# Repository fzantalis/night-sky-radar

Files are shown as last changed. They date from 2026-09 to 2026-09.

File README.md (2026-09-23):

# Night Sky Radar

A standalone desk instrument that shows which satellites are overhead right
now — and, more usefully, which of them you could actually *see* with the naked
eye if you walked outside.

No cloud service and no phone app. The device fetches orbital elements over
WiFi and propagates them itself with SGP4, so once it has data it keeps working
offline.

Two LEDs count down to the next visible pass, so you don't have to watch the
screen. Wave your hand to switch between satellites and asteroids.

---

## What it shows

**SKY mode** — a map of the sky above you. The centre is straight overhead, the
rim is the horizon, and north is up. A dot's size is its brightness; a pale
blue dot means *visible right now, go outside*. Meteor shower radiants appear as
soft patches when a shower is active and the sky is dark.

Only four conditions together make a satellite visible, and the device checks
all of them: it is more than 10° above the horizon, the sun is more than 6°
below yours, the satellite is still in sunlight, and it is brighter than
magnitude +4.5.

**NEO mode** — asteroid close approaches from NASA/JPL. Both axes change
meaning: the radius is the miss distance (the rim is 10 lunar distances), and
the angle is *when* it happens across a 30-day window. The ring at 1 lunar
distance is the Moon's orbit — anything inside it passes closer than the Moon.

**The LEDs** — one lit means a visible pass within 10 minutes, both mean within
5, and the pulse quickens as it approaches. They work in both modes.

---

## Parts

| Part | Notes |
|---|---|
| ESP32-S3-DevKitC-1 | ESP32-S3-WROOM-1 **N16R8** (16 MB flash, 8 MB PSRAM). The PSRAM is required — the framebuffer alone is 253 KB |
| 2.1" round TFT, 360×360 | **GC9B72** controller, 4-wire SPI |
| PAJ7620U2 gesture sensor | I²C, address `0x73` |
| 2 × WS2812 | Cut from an addressable strip |
| USB-C cable | Powers and flashes the board |

The `enclosure*.stl` files and the FreeCAD source are in the repository root.

---

## Wiring

> **Both the display and the gesture sensor are 3.3 V only.** 5 V on either
> will destroy it. Neither breakout has a regulator.

> **Never use GPIO 26–37 on an N16R8.** They are wired to the SPI flash and the
> octal PSRAM. 35/36/37 are broken out on the header, which makes them an easy
> trap.

**Display (GC9B72)**

| Display | ESP32-S3 |
|---|---|
| `VCC` | **3V3** |
| `GND` | GND |
| `SCL` | GPIO 12 |
| `SDA` | GPIO 11 |
| `CS` | GPIO 10 |
| `DC` | GPIO 13 |
| `RST` | GPIO 14 |
| `BL` | GPIO 9 |
| `SDO`, `TE` | leave unconnected |

`CS`/`SDA`/`SCL` are the S3's native SPI pins. Keep these leads short — the
panel is good for about 20 MHz on jumper wires.

**Gesture sensor (PAJ7620U2)**

| Sensor | ESP32-S3 |
|---|---|
| `VCC` | **3V3** |
| `GND` | GND |
| `SDA` | GPIO 17 |
| `SCL` | GPIO 18 |
| `INT` | GPIO 16 |

**LEDs (2 × WS2812)**

| Strip | ESP32-S3 |
|---|---|
| `+5V` | **3V3**, not 5V — see below |
| `GND` | GND |
| `DIN` | GPIO 15 |

The strip runs from 3.3 V deliberately. A WS2812 needs a logic high above
0.7 × VDD; on a 5 V supply that is 3.5 V, which an ESP32 GPIO cannot reach, so
5 V operation is marginal. At 3.3 V the threshold is 2.31 V and the same pin
clears it comfortably. It is slightly under the part's nominal minimum, which
costs nothing at the low brightness this instrument uses.

The strip is directional — wire the `DIN` end, not `DO`.

All pin assignments live in [`src/Pins.h`](src/Pins.h).

---

## Quick start

You need [PlatformIO](https://platformio.org/).

```bash
git clone https://github.com/fzantalis/night-sky-radar.git
cd night-sky-radar
cp src/secrets.h.example src/secrets.h     # then fill in your WiFi
pio run -t upload                          # firmware
pio run -t uploadfs                        # web UI files
```

On first boot the panel shows `SET LOCATION`. Find the device's IP in the
serial log (115200 baud), then open `http://<ip>/config` and enter your
latitude, longitude and altitude.

`http://<ip>/` gives the same dial in a browser — useful before you have the
panel wired, and it draws from the identical data the panel does.

**Controls.** Swipe left/right to change mode, up/down for brightness, wave to
wake the screen. In the browser, the arrow keys and space do the same. The BOOT
button also switches mode, as a fallback when no gesture sensor is attached.

---

## Tests

```bash
pio test -e native
```

224 tests covering the orbital mathematics, visibility rules, pass prediction
and data parsing. They run on the host, with no board attached — everything in
`lib/core/` is deliberately free of Arduino and ESP-IDF headers so it can be
tested that way.

---

## Data sources

| Source | Used for |
|---|---|
| [CelesTrak](https://celestrak.org/) | Orbital elements (TLE) |
| [NASA/JPL SBDB](https://ssd-api.jpl.nasa.gov/doc/cad.html) | Asteroid close approaches |
| [IMO](https://www.imo.net/) | Meteor shower almanac |

Provenance for every constant and data source, including the magnitude and
diameter relations, is recorded in [`docs/third-party/`](docs/third-party/).

---

## Licence

MIT — see [LICENSE](LICENSE).

This project includes a vendored copy of the
[dnwrnr/sgp4](https://github.com/dnwrnr/sgp4) library under the Apache License
2.0. See [NOTICE](NOTICE) and
[`lib/core/src/sgp4/LICENSE`](lib/core/src/sgp4/LICENSE).

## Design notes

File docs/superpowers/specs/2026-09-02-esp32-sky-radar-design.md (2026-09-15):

# ESP32-S3 Sky Radar — Design

**Date:** 2026-09-02
**Status:** Approved for implementation planning
**Scope of this spec:** Milestones M0–M2. M3–M7 are sketched for architectural context only.

## 1. Purpose

A standalone desk instrument that shows what is above you in near-Earth space on a circular radar-style display, with emphasis on objects you could actually walk outside and see with the naked eye.

The device is standalone: it fetches orbital elements a couple of times a day and does all propagation, visibility determination and projection itself. It keeps working through a router reboot. It is not a thin client for a tracking service.

Hardware target is an ESP32-S3-DevKitC-1 N16R8 (16 MB flash, 8 MB octal PSRAM). The final display is a GC9A01 240x240 round IPS SPI panel, not yet purchased. Until it arrives, the same renderer output is served to a browser as a 240x240 panel simulator.

## 2. Scope decisions

### In scope for M0–M2

- ISS and Tiangong tracking (CelesTrak `stations` group)
- The ~160 brightest catalogued objects (CelesTrak `visual` group)
- On-device SGP4 propagation
- Naked-eye visibility determination
- Forward pass prediction with countdowns
- A 240x240 circular web renderer that obeys the physical panel's constraints
- Native (PC) unit tests for the whole orbital/visibility core

### Deferred, but the architecture must not preclude them

- **M3** Starlink train detection — stream-filter the ~8000-object `starlink` group.
  **Corrected 2026-09-04:** the original wording said to filter by COSPAR launch
  designator, keeping launches from the last ~14 days. That is not implementable — a
  designator encodes the launch YEAR and the Nth launch of that year, never a date.
  The physically correct discriminator is **mean motion**: a fresh batch sits near
  350 km and is still raising orbit (~15.6 rev/day) while operational Starlinks sit
  at ~550 km (~15.06). Low and clustered is exactly what makes a train visible, and
  low is what mean motion measures. The designator remains useful as a grouping key
  for members of one launch.
- **M4** Meteor shower radiants — static almanac, rendered as a glowing sector
- **M5** NEO mode — JPL CAD API, Earth-centred, 10 lunar distances at the rim, time-scrubbed over 30 days rather than rendered live

  **Implemented 2026-09-05, with the time scrub resolved as an axis rather than a control.**
  "Time-scrubbed" left open how time reaches the dial. Making it a scrub *control*
  would have needed an input the device does not have and a renderer that holds its
  own clock state, breaking the dumb-polar-plotter rule. Instead **the angle itself is
  time**: 0 degrees is now, a full turn is the 30-day window, and radius is the miss
  distance with the rim at 10 lunar distances. Approaches march round towards the
  fixed "now" hand as their date arrives, so the whole window is legible at once with
  no control at all.

  Two further decisions, both departures worth recording:

  - **NEO mode does not require an observer location.** A close approach is an
    Earth-centred event, so `build()` checks the mode *before* the `hasLocation()`
    gate and the setup nag is suppressed there. The dial is meaningful on a device
    that has never been told where it is.
  - **Mode is not persisted.** After a power cut the instrument returns to SKY,
    because "is anything up right now" is the question it exists to answer.

  Switching is BOOT on the device and arrow keys or space in the browser, both
  through `/api/mode` so the device and every open browser agree on one mode.
  See `docs/third-party/NEO-CAD-PROVENANCE.md`.
- **M6** Panel renderer, gesture input, status LEDs

  **Implemented and verified on hardware 2026-09-15.** The hardware arrived
  different from the plan in all three respects, and the central bet of section
  3.1 is what absorbed it: because the core hands renderers finished
  `(r, theta)` pairs, **not one line of orbital maths changed**.

  - **Panel: GC9B72 360x360, not GC9A01 240x240.** LovyanGFX 1.2.29 carries a
    `Panel_GC9B72`, so no vendored driver. The framebuffer is 253 KB and lives
    in PSRAM; it cannot fit in internal RAM beside WiFi and ~200 tracked
    objects. SPI runs at 20 MHz rather than the bus maximum, because too-fast
    SPI does not fail cleanly — it yields intermittently corrupt pixels that
    read as a rendering bug.
  - **Input: PAJ7620U2 gesture sensor, not a rotary encoder or button.** Left
    and right switch mode, up and down walk a brightness ladder, wave clears
    the idle dim. BOOT survives as a fallback used only when the sensor does
    not answer on I2C.
  - **Status: two WS2812s, not a ring and not the onboard RGB.** The onboard
    part proved unreachable from software (see `tools/ledprobe`). Two pixels
    make the alert a countdown bar rather than a lamp.

  Three defects only the real hardware could have surfaced, all recorded in
  commit `e926ca6`: an RMT deadlock that hung the boot silently, panel colour
  flags that were doubly wrong, and the LED bar going dark in NEO mode because
  events were only attached on the SKY path.

- **M7** Captive-portal config, enclosure — gated on M6

**Revised 2026-09-04.** Two changes to the deferred list:

- **The NeoPixel bezel ring is dropped in favour of the board's own WS2812 on GPIO48**,
  and pulse notification moves forward from M7 into **M2**, where the visibility engine
  first makes "a pass worth alerting on" a real concept. The onboard LED loses the ring's
  rotating-sweep effects but keeps everything that matters (pulse, breathe, colour-code),
  needs no library (`neopixelWrite(RGB_BUILTIN, ...)` ships in the Arduino core), and draws
  ~5-10 mA dim-red against a 24-LED ring's ~720 mA at full white.
- **The magnetometer is deferred indefinitely** — see 3.4.

### Explicitly rejected

- **N2YO as a runtime data source.** Its REST API is well built, but sourcing positions from it makes the device a thin client that goes blank when WiFi hiccups, and binds the project to a free tier's rate limits. It is used instead as a **development-time test oracle** (see section 10).
- **Tracking all visible satellites server-side.** Loses the standalone quality that is the point of the project.
- **Meteors as tracked objects.** There is no per-meteor ephemeris. Only showers (radiant, peak date, ZHR) are real, and those are almanac data.
- **Starlink as a general naked-eye target.** Operational Starlinks with visors sit at roughly magnitude 5.5–7 and are not naked-eye objects. Only recently launched, still-clustered trains are worth displaying.

## 3. Architecture

### 3.1 The central decision

**Projection happens in the core; renderers are dumb polar plotters.**

The core computes each object's normalised polar coordinate — `r` in 0..1 and `theta` in degrees — and renderers only draw at (r, theta). Renderers contain no orbital geometry.

Consequences:

- The GC9A01 renderer is a small drawing routine, not a second implementation of the physics.
- SKY mode and NEO mode are the same renderer fed different projections, rather than two separate screens.
- The web view and the panel cannot drift apart, because neither contains anything that could drift.

### 3.2 The snapshot contract

The snapshot is the sole interface between core and renderers.

```json
{
  "t": 1756800000,
  "mode": "sky",
  "sun": { "alt": -12.4, "phase": "nautical" },
  "tleAgeHours": 6.2,
  "status": "ok",
  "blips": [
    { "id": 25544, "name": "ISS", "kind": "sat",
      "r": 0.58, "theta": 142.3,
      "mag": -3.1, "vis": "visible",
      "trail": [[0.61,138.0],[0.60,140.1]] }
  ],
  "events": [
    { "kind": "pass", "name": "ISS", "startsIn": 420,
      "maxEl": 67, "vis": "visible" }
  ]
}
```

`theta` is always in the **sky frame** (0 = true north). Rotation to the device's physical orientation is applied by the renderer at draw time from `HeadingSource`. This is what allows a magnetometer to be added at M7 without touching any maths.

### 3.3 Layers

**`core/` — pure C++, no Arduino or ESP-IDF headers.** TLE parsing (including COSPAR international designator extraction, needed at M3), SGP4 propagation, observer/topocentric geometry, solar position, the visibility engine, blip ranking, and projection into snapshots. Compiles natively on a PC.

**`firmware/` — everything platform-bound.** WiFi, NTP, the streaming CelesTrak fetcher, LittleFS TLE cache, `HeadingSource`, the HTTP/WebSocket server, and renderer implementations.

**`web/` — static assets served from LittleFS.** A 240x240 canvas panel simulator consuming the snapshot over WebSocket. Remains useful as a debug window after the panel arrives.

### 3.4 North as an interface

The renderer only ever calls `screenHeading()`. Three implementations:

- `FixedNorth` — always 0 degrees; used by the web simulator and during bring-up
- `ManualNorth` — a stored offset set once via the rotary encoder (M7)
- `MagnetometerNorth` — live compass heading (deferred indefinitely, see below)

This makes the magnetometer a swappable upgrade rather than a dependency.

**Decision 2026-09-04: the device is a STATIONARY INSTRUMENT, not a handheld pointer.**

A one-time north offset is only correct while the device does not move. A handheld that
rotates with you needs *live* heading, and only a magnetometer can supply that — GPS gives
position not facing, an accelerometer gives tilt, a gyro drifts without an absolute
reference, and a sun sighting is stale the moment you turn. A handheld would also need an
accelerometer for tilt compensation, because a magnetometer held angled at the sky reads
garbage.

That hardware is deferred. The device instead does the thing that is actually useful
outdoors: it states the bearing in words on the dial — `ISS 7m SE 142` — which you carry
in your head and use outside, where you are looking up at the sky rather than down at a
240-pixel screen that would ruin your dark adaptation anyway.

`FixedNorth` is therefore the shipping implementation. The interface stays so that
`ManualNorth` or `MagnetometerNorth` can be dropped in later without touching any maths.

### 3.5 Toolchain

PlatformIO with two environments: `esp32-s3-devkitc-1` (Arduino framework) for `firmware/`, and `native` for `core/` tests.

SGP4: vendor **dnwrnr/sgp4 (Apache-2.0)** rather than an Arduino-specific wrapper. It is plain C++ with no platform dependencies and drops directly into the natively-testable core.

Vallado's own reference implementation was the first choice, but CelesTrak now distributes it under **AGPL-3.0**, whose section 13 network clause would require the entire project to be AGPL once published. Correctness is still verified against Vallado's published test vectors, which are numerical data rather than code. Note that dnwrnr/sgp4 signals errors by throwing, so both build environments must enable C++ exceptions and the `Propagator` wrapper must ensure none escape.

## 4. Data sources

### 4.1 Orbital elements

```
GET celestrak.org/NORAD/elements/gp.php?GROUP=stations&FORMAT=tle   (M1)
GET celestrak.org/NORAD/elements/gp.php?GROUP=visual&FORMAT=tle     (M2, ~22 KB)
```

No API key, no account. Group queries map directly onto the project's scope.

**TLS:** use the ESP32 Arduino core's bundled Mozilla root store (`setCACertBundle` / `esp_crt_bundle`). Do not use `setInsecure()`, and do not pin a single root certificate — pinning means the device fails permanently when the CA rotates.

**Cadence:** every 12 hours, with exponential backoff on failure (1, 2, 4 … 60 minutes). ISS element sets are republished several times a day after reboosts, but 12 hours is well inside the accuracy budget.

**Caching:** write to LittleFS on every successful fetch, together with the fetch timestamp. A cold boot with no network must still draw a sky from cache.

### 4.2 Time

NTP, UTC. The ISS moves at 7.66 km/s, so one second of clock error is on the order of half a degree of sky — invisible at 240 px. NTP's typical tens of milliseconds is comfortably sufficient.

**If NTP has never succeeded, the device must refuse to propagate** and display an explicit error state rather than plotting from an unknown clock.

### 4.3 Observer position

Latitude, longitude and altitude stored in NVS, editable from the web configuration page. No GPS module. If unset, the device enters the setup state rather than assuming a default location.

## 5. The visibility engine

An object is treated as naked-eye visible when all four conditions hold:

1. **Above horizon** — elevation greater than 10 degrees. Below that, atmospheric extinction and ground obstructions make the claim unreliable.
2. **Observer in darkness** — solar altitude below −6 degrees (end of civil twilight).
3. **Satellite illuminated** — cylindrical Earth-shadow test: project the satellite's ECI position onto the Earth–Sun axis; it is eclipsed if it lies on the anti-sun side and its perpendicular distance from that axis is less than Earth's radius. A conical umbra/penumbra model is a later refinement for terminator-adjacent cases.
4. **Bright enough** — estimated apparent magnitude brighter than about +4.5.

### 5.1 Magnitude estimation

Apparent magnitude follows the standard Molczan/SeeSat-lineage relation, of the form `mag = stdMag − 15.75 + 2.5 · log10(range² / phaseFactor)`, where `phaseFactor` derives from the Sun–satellite–observer phase angle.

The exact constants and phase-factor form are to be pinned down against reference sources and locked in by unit test during implementation (see section 13).

### 5.2 Standard magnitudes

TLE data contains orbits, not brightnesses. `stdMag` values come from separately maintained magnitude files (the McCants/Molczan lineage).

**Approach:** bundle a static `stdMag` table in flash covering the `visual` group, with a conservative default for unrecognised NORAD IDs. This accepts a small maintenance debt in exchange for having no runtime dependency.

## 6. Pass prediction

The `events` list requires forward search: coarse SGP4 stepping to find horizon crossings, then bisection refinement for rise, maximum and set times.

Naively this is roughly 160 objects × 24 hours at 30-second steps, about 460,000 SGP4 evaluations — tens of seconds of continuous compute. This cannot run on the render path.

**Design:**

- Runs as a background task pinned to core 1 at low priority, with explicit yields so it can never starve the render loop or trip the task watchdog.
- Re-runs every 30–60 minutes; results are cached.
- A cheap geometric pre-filter discards objects whose inclination cannot bring them above the observer's horizon, before any propagation occurs.

The foreground loop performs only ~160 single-point SGP4 evaluations per snapshot at 1 Hz, which is negligible.

## 7. Renderer and viewport contract

### 7.1 The contract

Both renderers target a **240x240 logical canvas, circular, RGB565**. The web version displays this scaled 2–3x with `image-rendering: pixelated`, so the browser shows the real aliasing and real colour banding of the panel.

- **No hover, no tooltips, no mouse.** Input is a single rotary encoder: rotate and press. The web page binds arrow keys and Enter only.
- **Text is scarce.** At a legible ~10 px bitmap font, a bottom arc holds roughly 20 characters. UI strings must fit that budget, e.g. `ISS 7m 67`.
- **No smooth gradients.** 16-bit colour bands visibly; use flat fills and dithered rings.
- **Frame budget:** 240×240×2 = 115 KB per frame. A full SPI push at 40 MHz is ~23 ms, giving ~30 fps with DMA. Target **15 fps**.

### 7.2 SKY mode layout

Zenith at centre, horizon at the rim, `r = (90 − el) / 90` (equidistant azimuthal projection), so an overhead pass visibly dives toward the centre and back out.

- Rim circle at elevation 0
- Brighter **visibility floor ring** at elevation 10 degrees (r = 0.89)
- Faint rings at 30 and 60 degrees
- N/E/S/W ticks at the rim, rotating with `HeadingSource`
- Blips sized by magnitude, with a 3–5 point motion trail
- A low-alpha rotating sweep line; purely aesthetic, drawn on a sprite
- Bottom arc showing the next visible pass: name, countdown, maximum elevation

### 7.3 Blip cap

160 objects on a 240 px circle is unreadable. A hard cap of **~12 blips** applies, ranked by: currently visible, then brightness, then elevation. **The core performs this ranking**; the snapshot carries only drawable blips. Renderers never decide what matters.

### 7.4 Palette

A deep-red instrument palette. The device is looked at in darkness immediately before going outside, and long-wavelength red preserves rod dark-adaptation where the traditional phosphor green would bleach it.

- Ground: near-black
- Grid and rings: dim oxide red
- Text: brighter red
- **White/cyan reserved exclusively for "visible right now"**, so the single fact that matters is the only element that is not red

The NeoPixel bezel ring (M7) mirrors the same logic.

## 8. Failure behaviour

Failure states are **screen states**, not log lines. A device with no keyboard must explain itself on the dial.

| Condition | Behaviour |
|---|---|
| WiFi down, cached TLEs present | Continue propagating; dim "offline" mark on rim |
| NTP never succeeded | Refuse to propagate; blank sky and `NO TIME` |
| TLE fetch failed | Exponential backoff; continue serving cache |
| TLE age > 7 days | Amber age readout; still drawing, but declared degraded |
| First boot, no cache, no WiFi | Setup state: SoftAP and configuration page |
| Observer location unset | Setup state; do not assume a default position |

Governing rule: **the screen never shows a confident answer it cannot back.** Stale beats blank; stale-and-labelled beats stale-and-silent.

## 9. Memory and stability

TLS handshakes require roughly 40–50 KB of *internal* heap, which `WiFiClientSecure` does not draw from PSRAM. Concurrent HTTPS fetches, or a long-lived TLS client held open alongside the WebSocket server, are the standard cause of ESP32 projects that reboot daily for no visible reason.

**Rules:**

- Fetches are serialised, short-lived and fully torn down: open, stream-parse, close, free. Never two concurrently, never held open between fetches.
- The framebuffer and parsed TLE store live in PSRAM, away from the network stack.
- The pass-prediction task yields explicitly and is pinned to core 1 at low priority.

## 10. Testing

Three independent checks, all running natively on a PC with no flash cycle:

1. **SGP4 against Vallado's published verification vectors.** Known element sets, known expected state vectors. Passing this proves the propagator is correct, not merely plausible.
2. **Solar position and topocentric conversion** against known values for a fixed date and site.
3. **Full visibility verdicts diffed against N2YO `/visualpasses`** for the ISS at the observer's coordinates over five days. Pass start and end times should agree within a minute or two, and maximum elevation within a degree. This is the check that catches an inverted phase angle or a sign error in the shadow test.

## 11. Repository layout

```
core/            pure C++ — SGP4, geometry, solar, visibility, projection
  test/          native unit tests
firmware/        WiFi, NTP, fetchers, LittleFS cache, HeadingSource,
                 web server, renderers
web/             240x240 panel simulator, served from LittleFS
docs/superpowers/specs/
platformio.ini   two environments: esp32-s3-devkitc-1 (N16R8) and native
```

WiFi credentials live in a gitignored `secrets.h`. A captive portal is the correct long-term answer but belongs in M7.

## 12. Electrical and safety

**M0–M2 carry no electrical risk: nothing is wired.** The board runs bare on USB with no peripherals.

The electrical design — 3.3 V logic limits for the GC9A01, ESP32-S3 strapping pins (GPIO 0, 3, 45, 46), per-GPIO current limits, NeoPixel inrush and its magnetic interference with the magnetometer, and the power budget — is specified when M6/M7 are planned, once the specific panel and LED ring are chosen. Writing it before the parts are known would be guesswork.

Two hardware notes recorded now so they are not forgotten at purchase time:

- Modules sold as **HMC5883L are almost always QMC5883L** — a different manufacturer, different I2C address (0x0D rather than 0x1E) and a different register map. Buy knowingly, or choose a LIS3MDL or MMC5983MA instead.
- A NeoPixel ring encircling a magnetometer is an electromagnet. The sensor needs physical separation, and calibration must be performed in situ with the display and LEDs running.

## 13. Open items to verify during implementation

These are verification tasks, not undecided design questions:

1. ~~Confirm the licence of Vallado's reference SGP4.~~ **Resolved 2026-09-02:** it is AGPL-3.0, which was rejected; the project vendors dnwrnr/sgp4 (Apache-2.0) instead.
2. Pin down the exact apparent-magnitude formula constants and phase-factor form against reference sources; lock in by unit test.
3. Confirm the current source and licence of the McCants/Molczan standard magnitude table before bundling it.
4. Confirm magnetic declination for the observer's actual location at M7 time.

## 14. Milestones

| Milestone | Content | New hardware needed |
|---|---|---|
| M0 | WiFi, NTP, web server, empty radar with sweep | none |
| M1 | ISS and Tiangong; SGP4, topocentric, snapshot; native tests | none |
| M2 | Visibility engine, pass prediction, `visual` group; N2YO validation | none |
| M3 | Starlink train stream-filter | none |
| M4 | Meteor shower radiants | none |
| M5 | NEO mode; angle is time, radius is miss distance | none |
| M6 | GC9B72 360x360 renderer, gesture input, 2x WS2812 | done |
| M7 | Captive portal, enclosure, optional magnetometer | compass |

**This spec covers M0–M2.** M3 onward get their own specs.

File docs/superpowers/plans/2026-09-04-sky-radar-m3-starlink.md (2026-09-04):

# M3 — Starlink train detection

**Date:** 2026-09-04
**Prerequisite:** M2 merged (153 native tests, master at `d8aa2d8`).

**Goal:** show recently-launched Starlink "trains" — the tight strings of satellites that
*are* naked-eye visible for a week or so after launch — without drowning the dial in the
~8,000 operational Starlinks that are not.

**Process note:** M3–M5 run lighter than M0–M2. One task per feature, hardware-verified,
with review focused on the parts that touch the network or persistent storage.

---

## Spec correction — the original filter was not implementable

The design spec says: *"stream-filter the ~8000-object `starlink` group by COSPAR launch
designator, keeping only launches from the last ~14 days."*

**A COSPAR designator gives the launch YEAR and the Nth launch of that year — not a date.**
`25123A` is the 123rd launch of 2025; nothing in it says when that was. So "the last 14
days" cannot be derived from the designator alone.

**The physically correct discriminator is mean motion.** A freshly deployed batch sits at
roughly 350 km and is still raising orbit; operational Starlinks sit at ~550 km. Mean
motion follows directly:

| altitude | mean motion (rev/day) |
|---|---|
| ~350 km (fresh deployment) | ~15.6 |
| ~450 km (raising) | ~15.3 |
| ~550 km (operational) | ~15.06 |

This is also the *right* filter conceptually: what makes a train visible is that it is low
and tightly clustered, and low is exactly what mean motion measures. The launch designator
is still useful as a secondary grouping key — members of one train share it — so keep using
the `launchYear`/`launchNumber` that `parseTle` already extracts.

**Filter:** `meanMotionRevPerDay >= 15.35` AND the object's `launchYear` is the current year
or the previous one. Tune the threshold against real data during implementation and report
what it actually selects.

---

## Task 1: A genuinely streaming fetch

`tlefetcher::fetchGroup()` calls `http.getString()`, which materialises the entire response
body in one Arduino `String`. For `stations` (~4 KB) that is fine. For `starlink` it is
about **1.7 MB** against roughly 240 KB of free internal heap. It cannot work.

A comment in `TleFetcher.cpp` currently claims the parser streams and that this "is what
makes the 1.2 MB Starlink group tractable at M3". **That claim is false today** — the
parser holds three lines at a time, but only after the whole body is already in memory. A
reviewer flagged it during M0–M1. Delete or correct it.

**Add** (do not replace the existing function — `stations` and `visual` are small and the
current path works and is well tested):

```cpp
// Streams a CelesTrak group without ever holding the whole body. Reads the
// socket line by line, assembles one three-line element set at a time, parses
// it, and offers it to `keep`. Only accepted entries are retained.
//
// Returns the number of entries accepted, or -1 on transport failure.
using TleFilter = bool (*)(const Tle&);
int fetchGroupStreaming(const char* group, TleFilter keep,
                        std::vector<Tle>& out, int maxKeep);
```

Requirements:

- Read from `http.getStream()` with a bounded per-line buffer. Never accumulate the body.
- Reuse the same 5-root TLS trust store and the same serialised-fetch discipline — never
  two concurrent handshakes.
- Malformed triples are skipped, not fatal — `parseTle` already validates the checksum.
- Respect `maxKeep` so a pathological response cannot exhaust memory.
- Apply the existing parse-before-commit discipline: this feeds `tracked` directly, so
  validate the accepted count before disturbing anything.
- **Report peak internal heap during the fetch.** That is the number that proves it streams.

## Task 2: Wire trains into the scope

- Add the filter described above and fetch the `starlink` group on the same 12-hour cadence,
  after `stations` and `visual`, serialised.
- Cap the number of train members kept — a fresh batch is ~20–60 objects; 80 is a safe cap.
- Cache them like the other groups (group-aware `TleStore`, temp-and-rename).
- Give train members a distinguishable identity in the snapshot so the renderer can draw
  them as a group rather than as unrelated dots — add a `kind` field to `Blip`
  (`"sat"` / `"train"`), defaulting to `"sat"`.

## Task 3: Draw them as a train

In `data/radar.js`, render train members with a visually distinct treatment — they move
together in a line, and that is the whole reason they are worth showing. Keep the deep-red
palette; `#d8f4ff` stays reserved for "visible right now".

The roster should group train members under their launch designator rather than listing
sixty near-identical rows.

## Done criteria

1. The `starlink` group fetch completes on device without exhausting internal heap, with
   the peak figure reported.
2. The filter selects a plausible number of train members — report how many, their launch
   designators, and their mean motions, and sanity-check that against recent launches.
3. If no recent launch exists at the time of testing, the correct result is **zero train
   members**, and that must be reported as a pass, not worked around.
4. Existing `stations` and `visual` tracking is unaffected.
5. Native tests still pass, plus coverage for the filter predicate itself.

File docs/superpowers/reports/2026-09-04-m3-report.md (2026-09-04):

# M3 report — Starlink train detection

**Date:** 2026-09-04
**Branch:** `feat/sky-radar-m3`
**Plan:** `docs/superpowers/plans/2026-09-04-sky-radar-m3-starlink.md`

## Summary

All three tasks are implemented: a genuinely streaming CelesTrak fetch, the mean-motion
train filter (with one correction beyond the plan, justified against real data below),
and train rendering/rostering in the web renderer. 168 native tests pass (153 baseline +
13 for the filter predicate + 2 for `Blip::kind`/designator JSON fields). Hardware
verification is real but partial: the streaming mechanism itself was proven live against
real hardware and a real HTTPS response, and the failure path was proven live against the
*actual* `starlink` endpoint (which is currently declining requests from this network —
see below, not a bug). A full end-to-end successful `starlink` fetch at real 1.7 MB scale
could not be captured live in this session for the reason explained below; the memory
safety claim for that case rests on a live small-scale test of the identical code path
plus code inspection, not on wishful thinking.

## Task 1: Streaming fetch

Added `tlefetcher::fetchGroupStreaming()` in `src/TleFetcher.{h,cpp}`, alongside the
existing `fetchGroup()` (untouched — `stations`/`visual` still use it). It reads from
`http.getStreamPtr()` line-by-line into a fixed 160-byte stack buffer, holds at most one
three-line element set (`char triple[3][160]`) at a time, parses each with the existing
`parseTle()`, and offers it to a caller-supplied filter. Nothing scales with body size:
`Tle` is a plain-old-data struct (fixed char arrays, no `std::string`), there are no
`String` allocations in the hot loop, and the accepted-results vector is capped at
`maxKeep`. The stream is always drained to completion (or transport failure) regardless
of whether the cap was hit, both so `HTTPClient` tears down cleanly and so the raw
triple count (`totalParsed`) is a meaningful "did we get the real catalog" signal
independent of how many the filter kept.

I also deleted the false claim flagged in the plan: `parseTleText()`'s old comment said
holding three lines at a time is "what makes the 1.2 MB Starlink group tractable" — false,
since that function's `raw` parameter is already a fully-materialised `String` by the time
it runs. The comment now says so explicitly and points at `fetchGroupStreaming()` instead.

**Peak-heap evidence.** The real `starlink` endpoint was rate-gated for this whole session
(see below), so the live heap measurement is against the real `visual` endpoint (157
objects, ~26 KB body) through the *same* streaming code path, temporarily substituted in
place of `starlink` for one verification pass, then reverted before the final build:

```
[tle] streaming fetch of 'visual': 157 triple(s) parsed, 1 kept, min free heap 215124 bytes
```

Free heap at boot was ~275–284 KB; the floor during the fetch was 215,124 bytes — a
~60–68 KB drop, consistent with the ~40–50 KB `WiFiClientSecure`/`HTTPClient` TLS
overhead already documented in this file, not with body size. Because nothing in the loop
allocates per line or per triple (fixed buffers, POD `Tle`, capped output vector), the
same floor is expected running the identical loop 10,721 times (the real `starlink`
count, confirmed by direct analysis below) instead of 157 times. This is an inference from
code inspection plus a live test of the identical mechanism, not a live 1.7 MB-scale
measurement — see the hardware verification section for why, and what would close that
gap.

## Filter: mean motion, verified against real data, corrected once

Fetched the actual CelesTrak `starlink` group directly (`curl`, 2026-09-04, 1.80 MB,
32,163 lines, 10,721 objects) and analysed the full mean-motion distribution before
choosing anything:

- Median mean motion 15.317 rev/day; 8,441 of 10,721 objects (79%) round to 15.3 —
  this is the settled operational cluster the plan predicted (~15.06 was the plan's
  estimate for 550 km; the real figure the constellation actually sits at is closer to
  15.3, but the *shape* of the argument — a tight operational cluster with a gap above
  it — holds).
- **15.35 rev/day** (the plan's suggested threshold) sits just above that cluster and
  below every still-climbing object in the fetch. At that threshold + "launched this
  year or last" (2025 or 2026): **333 objects** matched.

**Spec correction found during verification, beyond the one already in the plan.**
Of those 333, ~280 were Starlink "Direct to Cell" satellites (CelesTrak tags them
`[DTC]` in the name) sitting permanently at 15.70–15.71 rev/day across **15+ different
launches from January 2026-09-04** — not because they were recently launched, but because
DTC satellites fly lower than the rest of the constellation *by design*. Mean motion
alone cannot tell "still climbing toward 550 km" apart from "operates permanently at
~350 km"; the year window doesn't help either, since DTC launches span the whole
current+previous year. Worse: DTC objects have **lower NORAD catalog numbers** than the
one genuine train in this fetch, and CelesTrak's group file is sorted by catalog number —
so a naive `maxKeep=80` cap would fill entirely with 8-month-old DTC stragglers and
**never reach the real train**, which carried the highest catalog numbers (69975–69998)
in the entire 10,721-object group.

Fix: `trainfilter::isTrainCandidate()` (`lib/core/src/TrainFilter.{h,cpp}`) additionally
excludes any name containing `DTC`, on top of the plan's mean-motion+year test. This is
a name-based exclusion, not a threshold change — I did not touch 15.35.

**What the corrected filter actually selects (2026-09-04 fetch):** 53 objects total.
Grouping by launch designator shows exactly one coherent train:

| designator | members | mean motion range |
|---|---|---|
| **2026-159** | **24** | 15.7518–15.7540 rev/day |
| 2025-018 | 2 | 15.3759–15.5467 |
| 2026-123 | 2 | 15.3540–15.3541 |
| 2026-147 | 2 | 15.7528–15.7533 |
| 2026-154 | 3 | 15.3539–15.3542 |
| 2026-157 | 3 | 15.3541–15.3542 |
| 13 other designators | 1 each | 15.35–15.98 |

2026-159's 24 members sit within a 0.0022 rev/day band of each other and carry the
highest NORAD catalog numbers in the whole group (69975–69998) — the signature of a
single batch deployed together and still climbing in formation. Sample members:
`STARLINK-38024` (69975), `STARLINK-37993`, `STARLINK-38057`, … `STARLINK-38091`
(69997). The other 29 objects are one-or-two-member stragglers scattered across 15
unrelated, mostly months-old launches — plausibly residual station-keeping/maneuver
noise, not visible trains. I did not filter these out further: `MAX_TRAIN=80` comfortably
holds all 53, and Task 3's "group by launch designator" roster naturally shows them as
their own tiny 1–3-member groups rather than false-conflating them with 2026-159.

**Native tests** for the predicate live in `test/test_trainfilter/test_trainfilter.cpp`:
threshold boundary, the year window (current/previous/two-years-back/future), the DTC
exclusion, a custom-threshold override, and three regression cases pinned to the real
`STARLINK-38024` / `STARLINK-11694 [DTC]` / `STARLINK-1008` objects from this exact
fetch.

## Task 2: Wiring into the scope

- `ScopeService::attemptRefresh()` fetches `starlink` via the streaming path, after
  `stations` and `visual`, still serialised (one `WiFiClientSecure` at a time, matching
  the existing constraint).
- **Important fix found during hardware testing, not in the original plan-following
  draft:** my first implementation gated `rebuildFromGroups()`/`markFetched()` on *all
  three* groups succeeding. Live testing immediately exposed why that's wrong — see
  "Hardware verification" below: a `starlink`-only failure would have taken
  `stations`/`visual` down with it, directly violating done-criterion 4 ("existing
  stations and visual tracking is unaffected"). Fixed: `stations`/`visual` success alone
  gates the rebuild and the freshness timestamp, exactly as before M3. `starlink`
  shares their cadence (fetched in the same cycle, after both) but neither blocks nor
  is blocked by them; on its own failure it falls back to whatever train roster is
  already cached on flash rather than erasing it.
- Plausibility (`tlecount::tleCountIsPlausible`) is checked against the **raw** parsed
  count (thousands of objects), never the filtered/accepted count — the latter is
  legitimately zero most days, and the existing plausibility gate rejects `count<=0`
  unconditionally (by design, for `stations`/`visual`, which should never be empty).
  Reusing it on the filtered count would treat every zero-train day as a failure.
- `MAX_TRAIN = 80` caps `fetchGroupStreaming()`'s output (real data needs 53).
  `MAX_TRACKED` raised 220→300 to leave room for it alongside the existing ~175
  stations+visual objects.
- Filtered results are cached via the *existing* `TleStore` (group `"starlink"`,
  temp-and-rename, unchanged) by re-serialising the already-parsed, already-filtered
  `Tle` entries back to three-line text (`Tle::name`/`line1`/`line2` are retained
  verbatim from the original fetch, so this is lossless).
- `Blip` gained `kind` (`"sat"`/`"train"`, default `"sat"`) and `launchYear`/
  `launchNumber` (populated for every blip, needed so the renderer can group trains by
  designator without guessing from the name string).

## Task 3: Rendering (`data/radar.js`)

- Train blips draw as a small diamond instead of a circle, plus a thin connecting line
  through all currently-drawn train members (sorted by sky radius) — the point is that
  they move together, so the connector is what actually shows that. Colour logic is
  unchanged (`P.text` / `P.visible`); `#d8f4ff` is still used only for `visible: true`,
  train or not.
- The roster groups train members by `launchYear`-`launchNumber` into one row
  ("`TRAIN 2026-159 ×24`", elevation range, representative bearing) instead of one row
  per satellite. Non-train blips are unaffected.

## Hardware verification

Board: COM6, `192.168.31.60` (confirmed unchanged via serial log on every boot).

1. **Firmware + filesystem build and flash cleanly.** `pio run -e esp32-s3-devkitc-1`
   succeeds (RAM 16.0%, Flash 19.1%); `-t upload` and `-t uploadfs` both succeeded
   multiple times during this session.
2. **Streaming mechanism verified live**, temporarily substituting `visual` for
   `starlink` in one build (reverted before the final build — confirmed by `git diff`
   showing no trace of it): `157 triple(s) parsed, 1 kept, min free heap 215124 bytes`,
   `plausible=1, saved=1`. Proves the line-by-line read, fixed-buffer parsing, filter
   callback, heap tracking, and cache round-trip all work against a real HTTPS
   connection end to end.
3. **The real `starlink` endpoint returned HTTP 403 to this network for this entire
   session**, with an explicit, documented reason in the response body:
   ```
   GP data has not updated since your last successful download
   of GROUP=starlink at 2026-09-04 18:13:31 UTC.
   Data is updated once every 2 hours.
   ```
   That "last successful download" was my own research `curl` fetch of the same
   endpoint (used for the threshold analysis above), made *before* any device testing
   began. CelesTrak's 2-hour freshness window means this network cannot get a fresh
   `starlink` response again until ~20:13 UTC — confirmed independently with a plain
   `curl` from this machine (`stations` returns 200, `starlink` returns 403, same
   moment). This is CelesTrak's own documented dedup policy, not rate-limiting abuse
   protection and not a bug in the streaming code.
4. **Failure path verified live, twice, including the critical fix.** Before the
   all-three-groups-gated draft was fixed: a wiped cache (`uploadfs`) plus the 403
   produced `[scope] refresh failed, retrying in 120 s` and **zero tracked objects** —
   i.e. `stations`/`visual`, which had just fetched and saved successfully, were
   discarded because of `starlink` alone. This is exactly the done-criterion-4
   violation described above, caught by hardware testing rather than review. After the
   fix, the identical scenario (wiped cache, `starlink` still 403) produced:
   ```
   [tle] fetched 3528 bytes for group stations
   [tle] fetched 26376 bytes for group visual
   [tle] streaming GET failed, code 403
   [scope] starlink streaming fetch: 0 triple(s) parsed, -1 kept as train candidates, min free heap 0 bytes, plausible=0, saved=0
   [scope] tracking 175 objects, psram free 8083131
   ```
   and `/api/scope` confirmed `"status":"ok"`, `"tleAgeHours":0.01`, 12 blips, all
   `"kind":"sat"` — stations/visual fresh and serving, train roster correctly empty
   (zero, not corrupted or stale-but-mislabelled) because this cycle's fetch failed and
   no prior successful `starlink` cache existed yet.
5. **Device left running the final, correct firmware and filesystem** (no diagnostic
   leftovers — confirmed via `git diff`/`grep` before the last build), with
   `stations`/`visual` tracking live and correct. `starlink` will retry automatically on
   the normal 12-hour cadence; the CelesTrak window reopens today at ~20:13 UTC, after
   which the next natural or forced (`uploadfs`) refresh cycle will exercise the real
   1.7 MB path end to end.

### What this leaves unverified

The one thing I could not directly observe this session: the actual `min free heap`
number during a *real* ~1.7 MB, 10,721-object `starlink` streaming fetch. The argument
that it will match the 157-object measurement (no per-iteration allocation; every buffer
is fixed-size; the only per-iteration heap-affecting call is `push_back` into a
`maxKeep`-capped vector) is sound but unverified live. If someone re-runs this after
20:13 UTC (or from a different network), the `[tle] streaming fetch of 'starlink':
... min free heap N bytes` log line is the number to check against ~215,000 (allowing
some margin — expect it to land close to the same floor, not meaningfully lower).

## Done-criteria checklist

1. `starlink` fetch completes without exhausting internal heap, peak reported —
   **partially direct**: mechanism proven live at small scale + code inspection for the
   full-scale case (see above), not a live full-scale number.
2. Filter selects a plausible number, designators and mean motions reported, sanity-
   checked against real data — **done**, see the table above (24-member 2026-159, real
   CelesTrak fetch).
3. If no recent launch exists, zero is a pass — **applies right now, differently than
   expected**: the live device currently reports zero train members, but because
   CelesTrak declined the request (403), not because no fresh launch exists — a real
   fresh launch (2026-159, 24 members) *does* exist in the data I fetched directly.
   This is reported as what it is, not glossed over.
4. Existing `stations`/`visual` tracking unaffected — **done, and verified live**
   (see the two-attempt comparison above); this required a real fix, not just following
   the plan.
5. Native tests pass, plus filter-predicate coverage — **done**: 168/168
   (153 baseline + 13 `test_trainfilter` + 2 `test_snapshot`).

## Deviations from the plan

- Added a DTC-name exclusion to the filter beyond the plan's literal mean-motion+year
  test, justified with real data (see above) — verified independently before changing
  anything, as instructed.
- `fetchGroupStreaming()`'s signature carries two extra optional out-parameters
  (`totalParsed`, `minFreeHeapOut`) beyond the plan's sketch, needed for the
  plausibility gate and the heap-reporting requirement respectively; both default to
  `nullptr` and are backward-compatible with the plan's signature.
- Decoupled `starlink`'s success from `stations`/`visual`'s (see above) — not something
  the plan called out explicitly, but required by done-criterion 4 and caught only by
  running on real hardware.
- Could not capture a live full-scale (1.7 MB) successful `starlink` fetch in this
  session due to CelesTrak's own freshness-dedup policy (see above), triggered by my
  own research fetch earlier in the session. Documented exactly what was and wasn't
  verified rather than fabricating a number.

## Follow-up (controller, same evening)

CelesTrak still returns **HTTP 403** for `GROUP=starlink` from this network, so the
full-scale (~1.7 MB) streaming heap figure remains inferred rather than measured. The body
of the 403 is 143 bytes and states CelesTrak's own freshness policy — it refuses a repeat
download of a group whose GP data has not changed since your last successful fetch.

**This is not a defect and will not affect normal operation.** The device fetches on a
12-hour cadence, far outside CelesTrak's dedup window; only our repeated same-day testing
tripped it. The next scheduled device cycle will exercise the real path.

What IS established: the streaming mechanism works end to end on hardware against a real
CelesTrak body, peak free internal heap held at 215,124 bytes, and nothing in the
implementation scales with body size (fixed 160-byte line buffers, POD `Tle`, capped output
vector). The filter was validated against the genuine 10,721-object catalogue fetched
earlier in the session.

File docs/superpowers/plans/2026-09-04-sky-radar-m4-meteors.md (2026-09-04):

# M4 — Meteor shower radiants

**Date:** 2026-09-04
**Prerequisite:** M3 merged (168 native tests).

**Goal:** show, on the same dial, where tonight's meteor shower radiant sits and whether the
shower is active — the one class of "space object worth going outside for" that has no
ephemeris at all.

**Process:** one dispatch, hardware-verified. Review focused on the almanac data itself,
because that is the only part that can be silently wrong.

---

## Why this is not satellite tracking

There is no per-meteor ephemeris and never will be. What is real and predictable is the
**shower**: a fixed radiant position on the celestial sphere, an activity window of dates,
a peak, and a rate (ZHR — zenithal hourly rate). That is almanac data, not orbital
mechanics. No network, no TLEs, no propagation.

So a radiant is a **fixed point in equatorial coordinates** (right ascension and
declination) that rises and sets like a star. Converting it to the dial's azimuth and
elevation is the only maths involved.

## Task 1: RA/Dec to horizontal coordinates

New `lib/core/src/Celestial.h/.cpp`:

```cpp
// Converts a fixed equatorial position (right ascension, declination, both
// degrees, J2000) to the observer's horizontal frame at a given instant.
// Radiants are fixed stars for this purpose - no propagation involved.
LookAngles radiantLookAngles(double raDeg, double decDeg,
                             const Observer& obs, int64_t unixSeconds);
```

Standard transform, using the project's existing `timeutils::gmstDegrees`:

- local sidereal time `LST = GMST + observer longitude`
- hour angle `H = LST - RA`
- `sin(el) = sin(dec)sin(lat) + cos(dec)cos(lat)cos(H)`
- `az = atan2(-sin(H)cos(dec), cos(lat)sin(dec) - sin(lat)cos(dec)cos(H))`, normalised to
  `[0,360)` measured from north increasing eastward

**Clamp the `asin` argument to `[-1,1]` before calling it.** This project has already been
bitten once by an unclamped `asin` producing NaN at the zenith, and `Topocentric.cpp` and
`Magnitude.cpp` both carry that guard now. Match them.

**Tests must pin the convention from both ends**, the way `test_magnitude`'s
backlit/fully-lit pair does. A test that passes under either sign convention is worthless —
this project has shipped an inverted phase angle exactly that way. At minimum:

- An object at the observer's zenith (declination = latitude, hour angle 0) is at elevation
  90 regardless of longitude or time.
- The celestial pole (dec = +90) sits due north at elevation equal to the observer's
  latitude, for any time — a pure symmetry check with no algebra.
- From the southern hemisphere the same pole is *below* the horizon.
- Azimuth is east of north for an object rising, west for one setting.

## Task 2: The almanac

New `lib/core/src/MeteorShowers.h/.cpp` — a static table:

```cpp
struct MeteorShower {
    const char* name;
    double raDeg;        // radiant, J2000
    double decDeg;
    int    peakMonth;    // 1-12
    int    peakDay;
    int    startMonth, startDay;   // activity window
    int    endMonth,   endDay;
    int    zhr;          // zenithal hourly rate at peak
};
```

**SOURCE THE DATA, DO NOT WRITE IT FROM MEMORY.** Use the International Meteor
Organization's published shower calendar (imo.net) or the IAU Meteor Data Center as the
citable source, and record in `docs/third-party/METEOR-ALMANAC-PROVENANCE.md` exactly where
each figure came from and when you retrieved it. This project has already shipped a wrong
TLE checksum and a physically impossible tolerance because I wrote constants from memory;
do not repeat that. If you cannot reach a citable source, say so and stop rather than
inventing plausible numbers.

Cover at least the major annual showers — Quadrantids, Lyrids, Eta Aquariids, Perseids,
Orionids, Leonids, Geminids, Ursids. Include the activity window, not just the peak; a
shower is worth showing for days either side.

Provide:

```cpp
// Showers active on the given date, soonest-peaking first. Handles windows
// that cross the new year.
std::vector<const MeteorShower*> activeShowers(int month, int day);
```

The year-crossing case is a real trap — the Quadrantids run from late December into early
January. Test it explicitly.

## Task 3: Put radiants on the dial

- Add a `radiants` array to `Snapshot`: name, `r`, `theta` (same normalised polar
  convention as blips), elevation, ZHR, and whether the shower is at peak.
- Include a radiant only when the shower is active **and** the radiant is above the horizon
  **and** the sun is below `MAX_SUN_ALT_DEG` — meteors are invisible in daylight, and a
  radiant below the horizon means the shower is not observable from here yet.
- Draw radiants distinctly from satellites: a soft glow or sector rather than a hard dot,
  since a radiant is a region of sky to watch rather than an object to point at. Deep-red
  palette; `#d8f4ff` stays reserved for "satellite visible right now".
- The roster gains a section listing active showers with their ZHR.

## Done criteria

1. `radiantLookAngles` passes symmetry tests that would fail under an inverted convention.
2. The almanac's provenance document names a real source and a retrieval date for every
   figure.
3. On device: report which showers the almanac considers active today (2026-09-04) and
   where their radiants sit. **If none are active, that is a correct result** — early
   September is genuinely quiet between the Perseids and the Orionids — and must be reported
   as a pass, not worked around by widening a window.
4. Existing satellite tracking, pass prediction and the LED are unaffected.
5. Native tests still pass, plus the new coverage.

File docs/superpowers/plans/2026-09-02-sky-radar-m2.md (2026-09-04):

# Sky Radar M2 Implementation Plan

> **For agentic workers:** REQUIRED SUB-SKILL: Use superpowers:subagent-driven-development (recommended) or superpowers:executing-plans to implement this plan task-by-task. Steps use checkbox (`- [ ]`) syntax for tracking.

**Prerequisite:** `docs/superpowers/plans/2026-09-02-sky-radar-m0-m1.md` complete, all its done-criteria verified.

**Goal:** The radar distinguishes objects that are merely overhead from objects you could actually walk outside and see, and tells you when the next visible pass starts.

**Architecture:** Four new pure functions in the core — solar position, Earth-shadow test, apparent magnitude, and the verdict that combines them — plus a pass predictor. On the board, prediction runs as its own FreeRTOS task on core 1 with its **own** propagators, never sharing state with the render path. The `visible` and `magnitude` fields already exist on `Blip` and are already wired to the `#d8f4ff` path in `radar.js`; M2 fills them in.

**Tech Stack:** Unchanged from M0–M1. Still zero third-party runtime libraries.

## Carried forward from M0-M1 execution — read before Task 1

These were found during M0-M1 and are recorded here because they change M2's plan.

**The PSRAM plan in Task 6 will not work as written.** `Propagator` holds
`std::unique_ptr<libsgp4::Tle>` and `std::unique_ptr<libsgp4::SGP4>`, allocated with
`std::make_unique`. A container allocator moves only the vector's array of `Tracked` —
two pointers plus the project's own ~200-byte `Tle` per element. **The SGP4 and
libsgp4::Tle payloads stay on the internal heap**, along with several `std::string`
allocations inside `libsgp4::Tle`. At 200 objects that is roughly 400+ small internal-heap
blocks totalling on the order of 250 KB, on a chip with ~300 KB of usable internal DRAM
after WiFi. It will not fit, and Task 6's own verification note ("if free PSRAM barely
moved, the allocator is not being used") will fire and be misdiagnosed as a wiring bug.
**The allocation decision has to live inside `Propagator`** — a PSRAM-aware allocator or
custom deleter — not in `ScopeService`'s vector. Secondary: `line1`/`line2` are stored
twice, once in the project's `Tle` and again inside `libsgp4::Tle` — about 28 KB of pure
duplication at 200 objects.

**`ScopeService` has no ownership boundary to hang Task 7's mutex on.** `tracked` and
`trails` are file-static globals in an anonymous namespace, and the `SnapshotProvider`
function-pointer indirection makes the coupling look more decoupled than it is. Task 7
needs a snapshot of the `Tle` list under a mutex; today the only way to get it is to reach
into a global while `rebuildFrom()` may be `clear()`-ing the vector. Hoist `tracked`/
`trails` into a struct with explicit accessors before Task 7, not during it.

**`build()` and `sampleTrails()` each independently propagate every tracked object.**
Acceptable at M1's 21 objects; M2 multiplies it by ~10 *and* forks a second core. Treat
this as a Task 6/7 prerequisite, not a deferred minor.

**`Propagator::positionAt` is no longer `const`,** deliberately: libsgp4 mutates through
const via `mutable IntegratorParams`, so a `const Propagator&` looked shareable and was
not. The class comment says NOT thread-safe. Task 7's "own propagators" rule is now
enforced by the type system rather than by hope.

**Deployment hazard:** `pio run -t uploadfs` erases the LittleFS partition but does not
touch the NVS `tlestore` timestamp, so a filesystem-only reflash leaves the device
believing its now-empty cache is fresh for up to 12 hours. Either pair `uploadfs` with an
NVS erase, or make boot treat a fresh timestamp with no cache file as stale.

**Test debt to pull forward:** the TLE two-digit-year boundary (57/00) is untested and was
deferred to M3, but M2's `visual` group is already almost entirely 20xx designators — cover
it here. `Propagator::positionAt`'s `catch(...)` and `look()`'s `rangeKm <= 0` guard are
both untested; M2's pass predictor propagates far past epoch where decay throws for real,
and its eclipse/magnitude engine adds more degenerate-geometry paths — cover them together.

**Toolchain:** `platform = espressif32` is unpinned while the code depends on version-
specific behaviour (that `setCACert()` accepts concatenated PEMs, and that no cert-bundle
data ships — the entire justification for the 5-root trust store). Pin it.

---

## Global Constraints

All M0–M1 global constraints still apply in full. Additions specific to M2:

- **Visibility requires all four conditions** (spec §5): elevation > 10°, solar altitude < −6°, satellite sunlit, apparent magnitude < +4.5. No condition may be dropped or made configurable at M2.
- **The magnitude formula is `mag = stdMag + 5·log₁₀(range_km / 1000) − 2.5·log₁₀(phaseFactor)`** with `phaseFactor = (π − φ)·cos φ + sin φ`, where φ is the Sun–satellite–observer phase angle in radians. This normalisation is self-consistent with the definition of `stdMag` (brightness at 1000 km range and 90° phase) and that self-consistency is asserted by a unit test. **This is spec §13 item 2** — the form is locked in by test, then validated end-to-end against N2YO in Task 9.
- **Pass prediction never touches the render path's propagators.** `Propagator::positionAt` mutates its `elsetrec` internally, so a shared instance is a data race. The prediction task copies the `Tle` list under a mutex and builds its own propagators.
- **The tracked-object vector lives in PSRAM.** ~200 objects × ~900 bytes of `elsetrec` is ~180 KB, which must not compete with the TLS handshake's internal heap.
- **Prediction yields.** The task must call `vTaskDelay(1)` regularly so it can never starve the render loop or trip the task watchdog.
- **N2YO is a development-time oracle only.** No N2YO call may ever appear in firmware. The API key lives outside the repository and is never committed.

---

## File Structure

New files only; everything else is modified in place.

```
lib/core/src/
  Solar.h/.cpp            sun position in the propagator's frame; sun altitude
  Eclipse.h/.cpp          cylindrical Earth-shadow test
  Magnitude.h/.cpp        phase angle and apparent magnitude
  StdMagTable.h/.cpp      NORAD id -> standard magnitude, with documented default
  Visibility.h/.cpp       the four-condition verdict
  PassPredictor.h/.cpp    horizon-crossing search with bisection refinement
src/
  PsramAllocator.h        std-compatible allocator backed by SPIRAM
  PassTask.h/.cpp         FreeRTOS prediction task and its mutex-guarded cache
test/
  test_solar/             solstice, equinox, distance, altitude sign
  test_eclipse/           lit, umbral, off-axis
  test_magnitude/         self-consistency, inverse-square, phase, degenerate
  test_visibility/        each rejection path independently
  test_passpredictor/     ordering, refinement, inclination pre-filter
  test_validation/        N2YO fixture diff (opt-in, skipped without a fixture)
  fixtures/               n2yo_passes.txt, produced by tools/fetch_n2yo.sh
tools/
  fetch_n2yo.sh           captures the oracle fixture; never runs on the board
docs/third-party/
  STDMAG-PROVENANCE.md    where the magnitude table came from
```

---

## Task 1: Solar position

Everything about visibility depends on where the Sun is. This uses the low-precision Astronomical Almanac series, accurate to roughly 0.01°, which is three orders of magnitude better than this project needs.

**Files:**
- Create: `lib/core/src/Solar.h`, `lib/core/src/Solar.cpp`
- Test: `test/test_solar/test_solar.cpp`

**Interfaces:**
- Consumes: `Vec3` (M1 Task 1), `Observer`, `look` (M1 Task 5), `timeutils` (M1 Task 2)
- Produces:
  - `Vec3 sunEci(double jd)` — km, same equatorial frame the propagator outputs
  - `double sunDeclinationDeg(double jd)`
  - `double sunAltitudeDeg(const Observer& obs, int64_t unixSeconds)`

- [ ] **Step 1: Write the failing test**

Create `test/test_solar/test_solar.cpp`:

```cpp
#include <unity.h>
#include <cmath>
#include "Solar.h"
#include "TimeUtils.h"
#include "Observer.h"

// Unix timestamps for 12:00 UTC on notable dates in 2000.
static const long long T_J2000    = 946728000LL;  // 2000-01-01, dec approx -23.0
static const long long T_EQUINOX  = 953553600LL;  // 2000-03-20, dec approx 0
static const long long T_SOLSTICE = 961588800LL;  // 2000-06-21, dec approx +23.44

static double jdOf(long long unixSeconds) {
    return timeutils::julianDate(unixSeconds);
}

void test_sun_distance_is_about_one_au(void) {
    // Earth-Sun distance varies between roughly 147.1 and 152.1 million km.
    const double r = sunEci(jdOf(T_J2000)).norm();
    TEST_ASSERT_TRUE(r > 1.44e8);
    TEST_ASSERT_TRUE(r < 1.53e8);
}

void test_sun_is_nearest_in_early_january(void) {
    // Perihelion is in the first week of January, aphelion in early July.
    const double rJan = sunEci(jdOf(T_J2000)).norm();
    const double rJul = sunEci(jdOf(T_SOLSTICE + 15LL * 86400LL)).norm();
    TEST_ASSERT_TRUE(rJan < rJul);
}

void test_declination_at_new_year(void) {
    TEST_ASSERT_DOUBLE_WITHIN(0.3, -23.0, sunDeclinationDeg(jdOf(T_J2000)));
}

void test_declination_near_zero_at_march_equinox(void) {
    TEST_ASSERT_DOUBLE_WITHIN(0.5, 0.0, sunDeclinationDeg(jdOf(T_EQUINOX)));
}

void test_declination_near_maximum_at_june_solstice(void) {
    TEST_ASSERT_DOUBLE_WITHIN(0.3, 23.44, sunDeclinationDeg(jdOf(T_SOLSTICE)));
}

void test_declination_never_exceeds_obliquity(void) {
    for (long long t = T_J2000; t < T_J2000 + 400LL * 86400LL; t += 86400LL * 7LL) {
        const double d = sunDeclinationDeg(jdOf(t));
        TEST_ASSERT_TRUE(std::fabs(d) <= 23.5);
    }
}

void test_sun_is_up_at_local_noon_and_down_at_local_midnight(void) {
    // Greenwich: local noon is 12:00 UTC, local midnight is 00:00 UTC.
    Observer greenwich{51.48, 0.0, 0.0};
    const double noon     = sunAltitudeDeg(greenwich, T_EQUINOX);
    const double midnight = sunAltitudeDeg(greenwich, T_EQUINOX - 43200LL);
    TEST_ASSERT_TRUE(noon > 20.0);
    TEST_ASSERT_TRUE(midnight < -20.0);
}

void test_sun_altitude_stays_in_range(void) {
    Observer obs{37.98, 23.73, 0.1};
    for (long long t = T_J2000; t < T_J2000 + 86400LL * 3LL; t += 997LL) {
        const double a = sunAltitudeDeg(obs, t);
        TEST_ASSERT_TRUE(a >= -90.5);
        TEST_ASSERT_TRUE(a <= 90.5);
    }
}

void test_polar_night_at_the_north_pole_in_january(void) {
    Observer pole{89.9, 0.0, 0.0};
    // The Sun cannot rise at the pole in January regardless of the hour.
    for (long long t = T_J2000; t < T_J2000 + 86400LL; t += 3600LL) {
        TEST_ASSERT_TRUE(sunAltitudeDeg(pole, t) < 0.0);
    }
}

int main(int, char**) {
    UNITY_BEGIN();
    RUN_TEST(test_sun_distance_is_about_one_au);
    RUN_TEST(test_sun_is_nearest_in_early_january);
    RUN_TEST(test_declination_at_new_year);
    RUN_TEST(test_declination_near_zero_at_march_equinox);
    RUN_TEST(test_declination_near_maximum_at_june_solstice);
    RUN_TEST(test_declination_never_exceeds_obliquity);
    RUN_TEST(test_sun_is_up_at_local_noon_and_down_at_local_midnight);
    RUN_TEST(test_sun_altitude_stays_in_range);
    RUN_TEST(test_polar_night_at_the_north_pole_in_january);
    return UNITY_END();
}
```

- [ ] **Step 2: Run the test to verify it fails**

```bash
pio test -e native -f test_solar
```

Expected: FAIL — `fatal error: Solar.h: No such file or directory`.

- [ ] **Step 3: Write the minimal implementation**

Create `lib/core/src/Solar.h`:

```cpp
#pragma once

#include <cstdint>
#include "Vec3.h"
#include "Observer.h"

// Geocentric position of the Sun in kilometres, in the same equatorial frame
// the propagator outputs. Uses the low-precision Astronomical Almanac series,
// good to roughly 0.01 degrees - far better than this application needs.
Vec3 sunEci(double jd);

double sunDeclinationDeg(double jd);

// Altitude of the Sun above the observer's horizon, in degrees. Negative means
// below the horizon. Spec section 5 requires this to be below -6 for an object
// to count as visible.
double sunAltitudeDeg(const Observer& obs, int64_t unixSeconds);
```

Create `lib/core/src/Solar.cpp`:

```cpp
#include "Solar.h"

#include <cmath>

#include "TimeUtils.h"
#include "Topocentric.h"

namespace {

constexpr double PI      = 3.14159265358979323846;
constexpr double DEG2RAD = PI / 180.0;
constexpr double RAD2DEG = 180.0 / PI;
constexpr double AU_KM   = 149597870.7;

double norm360(double d) {
    d = std::fmod(d, 360.0);
    if (d < 0.0) d += 360.0;
    return d;
}

}  // namespace

Vec3 sunEci(double jd) {
    const double n = jd - timeutils::JD_J2000;

    const double L = norm360(280.460 + 0.9856474 * n);   // mean longitude
    const double g = norm360(357.528 + 0.9856003 * n);   // mean anomaly
    const double gRad = g * DEG2RAD;

    // Apparent ecliptic longitude: mean longitude plus the equation of centre.
    const double lambda =
        (L + 1.915 * std::sin(gRad) + 0.020 * std::sin(2.0 * gRad)) * DEG2RAD;

    const double eps = (23.439 - 0.0000004 * n) * DEG2RAD;   // obliquity

    // Distance in astronomical units, then kilometres.
    const double rAu = 1.00014
                     - 0.01671 * std::cos(gRad)
                     - 0.00014 * std::cos(2.0 * gRad);
    const double r = rAu * AU_KM;

    // Ecliptic to equatorial.
    return Vec3{ r * std::cos(lambda),
                 r * std::cos(eps) * std::sin(lambda),
                 r * std::sin(eps) * std::sin(lambda) };
}

double sunDeclinationDeg(double jd) {
    const Vec3 s = sunEci(jd);
    const double r = s.norm();
    if (r <= 0.0) return 0.0;
    return std::asin(s.z / r) * RAD2DEG;
}

double sunAltitudeDeg(const Observer& obs, int64_t unixSeconds) {
    const double jd   = timeutils::julianDate(unixSeconds);
    const double gmst = timeutils::gmstDegrees(jd);
    // Reuse the already-tested topocentric transform rather than repeating it.
    return look(sunEci(jd), obs, gmst).elDeg;
}
```

- [ ] **Step 4: Run the test to verify it passes**

```bash
pio test -e native -f test_solar
```

Expected: PASS — 9 tests, 0 failures.

If the solstice and equinox tests fail together by a similar amount, the obliquity term is wrong. If declination is right but altitude is wrong, the fault is in the GMST pairing, not here.

- [ ] **Step 5: Commit**

```bash
git add lib/core/src/Solar.h lib/core/src/Solar.cpp test/test_solar
git commit -m "feat(core): add solar position, declination and observer sun altitude"
```

---

## Task 2: Earth-shadow test

Whether the satellite is lit. Cylindrical model per spec §5 condition 3 — the conical umbra refinement is explicitly out of scope.

**Files:**
- Create: `lib/core/src/Eclipse.h`, `lib/core/src/Eclipse.cpp`
- Test: `test/test_eclipse/test_eclipse.cpp`

**Interfaces:**
- Consumes: `Vec3` (M1 Task 1)
- Produces: `bool isSunlit(const Vec3& satEci, const Vec3& sunEci)`, `constexpr double EARTH_RADIUS_KM = 6378.137`

- [ ] **Step 1: Write the failing test**

Create `test/test_eclipse/test_eclipse.cpp`:

```cpp
#include <unity.h>
#include "Eclipse.h"
#include "Vec3.h"

// Sun placed a long way down the +x axis for all these cases.
static const Vec3 SUN{1.496e8, 0.0, 0.0};

void test_satellite_on_the_sunward_side_is_lit(void) {
    Vec3 sat{6778.0, 0.0, 0.0};   // 400 km up, directly toward the Sun
    TEST_ASSERT_TRUE(isSunlit(sat, SUN));
}

void test_satellite_directly_behind_earth_is_eclipsed(void) {
    Vec3 sat{-6778.0, 0.0, 0.0};  // 400 km up on the anti-sun side
    TEST_ASSERT_FALSE(isSunlit(sat, SUN));
}

void test_satellite_behind_earth_but_outside_the_shadow_cylinder_is_lit(void) {
    // Anti-sun side, but displaced further from the Earth-Sun axis than one
    // Earth radius, so the shadow cylinder misses it.
    Vec3 sat{-6778.0, 7000.0, 0.0};
    TEST_ASSERT_TRUE(isSunlit(sat, SUN));
}

void test_satellite_just_inside_the_shadow_cylinder_is_eclipsed(void) {
    Vec3 sat{-6778.0, 6000.0, 0.0};   // 6000 km off-axis, inside 6378
    TEST_ASSERT_FALSE(isSunlit(sat, SUN));
}

void test_terminator_crossing_is_monotonic(void) {
    // Sweeping the off-axis distance outward must cross from eclipsed to lit
    // exactly once, at the Earth's radius.
    bool sawEclipsed = false, sawLit = false;
    for (double y = 0.0; y < 12000.0; y += 100.0) {
        const bool lit = isSunlit(Vec3{-6778.0, y, 0.0}, SUN);
        if (!lit) {
            sawEclipsed = true;
            TEST_ASSERT_FALSE(sawLit);   // must not flip back
        } else {
            sawLit = true;
        }
    }
    TEST_ASSERT_TRUE(sawEclipsed);
    TEST_ASSERT_TRUE(sawLit);
}

void test_high_altitude_satellite_over_the_pole_stays_lit(void) {
    // A satellite far above the pole is never in the equatorial shadow when the
    // Sun lies in the equatorial plane.
    Vec3 sat{-30000.0, 0.0, 25000.0};
    TEST_ASSERT_TRUE(isSunlit(sat, SUN));
}

void test_zero_sun_vector_defaults_to_lit(void) {
    // Degenerate input must not produce NaN-driven behaviour.
    TEST_ASSERT_TRUE(isSunlit(Vec3{-6778.0, 0.0, 0.0}, Vec3{0.0, 0.0, 0.0}));
}

int main(int, char**) {
    UNITY_BEGIN();
    RUN_TEST(test_satellite_on_the_sunward_side_is_lit);
    RUN_TEST(test_satellite_directly_behind_earth_is_eclipsed);
    RUN_TEST(test_satellite_behind_earth_but_outside_the_shadow_cylinder_is_lit);
    RUN_TEST(test_satellite_just_inside_the_shadow_cylinder_is_eclipsed);
    RUN_TEST(test_terminator_crossing_is_monotonic);
    RUN_TEST(test_high_altitude_satellite_over_the_pole_stays_lit);
    RUN_TEST(test_zero_sun_vector_defaults_to_lit);
    return UNITY_END();
}
```

- [ ] **Step 2: Run the test to verify it fails**

```bash
pio test -e native -f test_eclipse
```

Expected: FAIL — `fatal error: Eclipse.h: No such file or directory`.

- [ ] **Step 3: Write the minimal implementation**

Create `lib/core/src/Eclipse.h`:

```cpp
#pragma once
#include "Vec3.h"

constexpr double EARTH_RADIUS_KM = 6378.137;

// Cylindrical Earth-shadow test (spec section 5, condition 3). The satellite is
// eclipsed when it lies on the anti-sun side of the Earth AND its perpendicular
// distance from the Earth-Sun axis is less than one Earth radius.
//
// This ignores the penumbra and the Sun's angular size, so it is wrong only in a
// narrow band at the terminator. A conical model is a deliberate non-goal.
bool isSunlit(const Vec3& satEci, const Vec3& sunEci);
```

Create `lib/core/src/Eclipse.cpp`:

```cpp
#include "Eclipse.h"

bool isSunlit(const Vec3& satEci, const Vec3& sunEci) {
    const Vec3 sunHat = sunEci.unit();

    // Degenerate sun vector: fail open rather than declaring a permanent
    // eclipse, which would silently hide every object.
    if (sunHat.norm() <= 0.0) return true;

    const double along = satEci.dot(sunHat);

    // On the sunward side of the terminator plane: always lit.
    if (along > 0.0) return true;

    // Perpendicular distance from the Earth-Sun axis.
    const Vec3 perp = satEci - sunHat * along;
    return perp.norm() >= EARTH_RADIUS_KM;
}
```

- [ ] **Step 4: Run the test to verify it passes**

```bash
pio test -e native -f test_eclipse
```

Expected: PASS — 7 tests, 0 failures.

- [ ] **Step 5: Commit**

```bash
git add lib/core/src/Eclipse.h lib/core/src/Eclipse.cpp test/test_eclipse
git commit -m "feat(core): add cylindrical Earth-shadow test"
```

---

## Task 3: Phase angle, apparent magnitude, and the standard magnitude table

Spec §13 item 2 lands here. The formula's normalisation is pinned by a self-consistency test: at exactly 1000 km range and 90° phase — the definition of `stdMag` — the function must return `stdMag` unchanged. Any formula with the wrong constant fails that test immediately.

**Files:**
- Create: `lib/core/src/Magnitude.h`, `lib/core/src/Magnitude.cpp`
- Create: `lib/core/src/StdMagTable.h`, `lib/core/src/StdMagTable.cpp`
- Create: `docs/third-party/STDMAG-PROVENANCE.md`
- Test: `test/test_magnitude/test_magnitude.cpp`

**Interfaces:**
- Consumes: `Vec3` (M1 Task 1)
- Produces:
  - `double phaseAngleRad(const Vec3& satEci, const Vec3& sunEci, const Vec3& siteEci)`
  - `double apparentMagnitude(double stdMag, double rangeKm, double phaseRad)`
  - `constexpr double DEFAULT_STD_MAG = 2.5`
  - `double stdMagFor(int noradId)`

- [ ] **Step 1: Write the failing test**

Create `test/test_magnitude/test_magnitude.cpp`:

```cpp
#include <unity.h>
#include <cmath>
#include "Magnitude.h"
#include "StdMagTable.h"
#include "Vec3.h"

static constexpr double PI = 3.14159265358979323846;

// The defining condition of a standard magnitude: 1000 km range, 90 degree
// phase angle. If the formula's constant is wrong, this is the test that says so.
void test_at_reference_conditions_returns_std_mag(void) {
    TEST_ASSERT_DOUBLE_WITHIN(1e-9, -1.8,
        apparentMagnitude(-1.8, 1000.0, PI / 2.0));
}

void test_doubling_range_dims_by_inverse_square(void) {
    const double near = apparentMagnitude(-1.8, 1000.0, PI / 2.0);
    const double far  = apparentMagnitude(-1.8, 2000.0, PI / 2.0);
    TEST_ASSERT_DOUBLE_WITHIN(1e-6, 5.0 * std::log10(2.0), far - near);
}

void test_full_phase_is_brighter_than_quarter_phase(void) {
    const double full    = apparentMagnitude(-1.8, 1000.0, 0.0);
    const double quarter = apparentMagnitude(-1.8, 1000.0, PI / 2.0);
    TEST_ASSERT_TRUE(full < quarter);           // lower magnitude is brighter
    TEST_ASSERT_DOUBLE_WITHIN(0.01, -1.243, full - quarter);
}

void test_brightness_decreases_monotonically_with_phase_angle(void) {
    double prev = -99.0;
    for (double phi = 0.0; phi < PI * 0.98; phi += 0.05) {
        const double m = apparentMagnitude(-1.8, 1000.0, phi);
        TEST_ASSERT_TRUE(m > prev);
        prev = m;
    }
}

void test_back_lit_satellite_is_finite_and_very_dim(void) {
    // Phase angle pi means the observer sees the unlit face. The phase factor
    // collapses to zero, so the result must be clamped rather than infinite.
    const double m = apparentMagnitude(-1.8, 1000.0, PI);
    TEST_ASSERT_TRUE(std::isfinite(m));
    TEST_ASSERT_TRUE(m > 20.0);
}

void test_zero_range_is_finite(void) {
    TEST_ASSERT_TRUE(std::isfinite(apparentMagnitude(-1.8, 0.0, PI / 2.0)));
}

void test_phase_angle_pi_when_the_satellite_is_backlit(void) {
    // Sun far along +x; observer at 6378, satellite at 7000 - so the satellite
    // sits BETWEEN the observer and the Sun and the observer sees its unlit
    // face. That is phase angle pi, not zero.
    Vec3 sun{1.496e8, 0.0, 0.0};
    Vec3 sat{7000.0, 0.0, 0.0};
    Vec3 site{6378.0, 0.0, 0.0};
    TEST_ASSERT_DOUBLE_WITHIN(0.01, PI, phaseAngleRad(sat, sun, site));
}

void test_phase_angle_zero_when_the_satellite_is_fully_lit(void) {
    // Sun behind the OBSERVER: sun, then observer, then satellite on the
    // anti-sun side. The observer sees the fully lit face - phase angle zero.
    //
    // This test and the backlit one above are a matched pair, and together they
    // are the only thing that pins the direction convention. Note that the
    // 90-degree test below returns 90 under EITHER convention, so it cannot
    // discriminate: dropping either of these two would let an inverted
    // phaseAngleRad through, which would make every satellite look brightest
    // exactly when it is unlit.
    Vec3 sun{1.496e8, 0.0, 0.0};
    Vec3 sat{-7000.0, 0.0, 0.0};
    Vec3 site{6378.0, 0.0, 0.0};
    TEST_ASSERT_DOUBLE_WITHIN(0.01, 0.0, phaseAngleRad(sat, sun, site));
}

void test_phase_angle_ninety_degrees(void) {
    // Observer displaced perpendicular to the Sun direction, at the same
    // distance scale as the satellite's offset from it.
    Vec3 sun{1.496e8, 0.0, 0.0};
    Vec3 sat{0.0, 0.0, 0.0};
    Vec3 site{0.0, 1000.0, 0.0};
    TEST_ASSERT_DOUBLE_WITHIN(0.01, PI / 2.0, phaseAngleRad(sat, sun, site));
}

void test_phase_angle_always_in_range(void) {
    Vec3 sun{1.496e8, 0.0, 0.0};
    for (double a = -8000.0; a <= 8000.0; a += 977.0) {
        const double phi = phaseAngleRad(Vec3{a, a * 0.3, -a * 0.7}, sun,
                                         Vec3{6378.0, a * 0.1, 0.0});
        TEST_ASSERT_TRUE(phi >= 0.0);
        TEST_ASSERT_TRUE(phi <= PI + 1e-9);
    }
}

void test_iss_has_a_known_standard_magnitude(void) {
    TEST_ASSERT_DOUBLE_WITHIN(0.01, -1.8, stdMagFor(25544));
}

void test_unknown_object_gets_the_documented_default(void) {
    TEST_ASSERT_DOUBLE_WITHIN(1e-9, DEFAULT_STD_MAG, stdMagFor(999999));
}

int main(int, char**) {
    UNITY_BEGIN();
    RUN_TEST(test_at_reference_conditions_returns_std_mag);
    RUN_TEST(test_doubling_range_dims_by_inverse_square);
    RUN_TEST(test_full_phase_is_brighter_than_quarter_phase);
    RUN_TEST(test_brightness_decreases_monotonically_with_phase_angle);
    RUN_TEST(test_back_lit_satellite_is_finite_and_very_dim);
    RUN_TEST(test_zero_range_is_finite);
    RUN_TEST(test_phase_angle_pi_when_the_satellite_is_backlit);
    RUN_TEST(test_phase_angle_zero_when_the_satellite_is_fully_lit);
    RUN_TEST(test_phase_angle_ninety_degrees);
    RUN_TEST(test_phase_angle_always_in_range);
    RUN_TEST(test_iss_has_a_known_standard_magnitude);
    RUN_TEST(test_unknown_object_gets_the_documented_default);
    return UNITY_END();
}
```

- [ ] **Step 2: Run the test to verify it fails**

```bash
pio test -e native -f test_magnitude
```

Expected: FAIL — `fatal error: Magnitude.h: No such file or directory`.

- [ ] **Step 3: Write the magnitude implementation**

Create `lib/core/src/Magnitude.h`:

```cpp
#pragma once
#include "Vec3.h"

// Sun-satellite-observer angle in radians, in [0, pi]. Zero means the satellite
// is fully lit as seen from the observer; pi means the observer sees its
// unlit face.
double phaseAngleRad(const Vec3& satEci, const Vec3& sunEci, const Vec3& siteEci);

// Apparent visual magnitude.
//
//   mag = stdMag + 5*log10(range_km / 1000) - 2.5*log10(phaseFactor)
//   phaseFactor = (pi - phi)*cos(phi) + sin(phi)
//
// A standard magnitude is defined as the object's brightness at 1000 km range
// and 90 degrees phase, and this normalisation reproduces exactly that: at
// phi = pi/2 the phase factor is 1 and the range term is 0, so the result is
// stdMag. That identity is asserted by test and must not be broken.
//
// Spec section 13 item 2: validated end-to-end against N2YO in Task 9.
double apparentMagnitude(double stdMag, double rangeKm, double phaseRad);
```

Create `lib/core/src/Magnitude.cpp`:

```cpp
#include "Magnitude.h"

#include <cmath>

namespace {

constexpr double PI = 3.14159265358979323846;

// Floors that keep degenerate geometry finite instead of producing infinities
// that would propagate into the snapshot.
constexpr double MIN_PHASE_FACTOR = 1e-6;
constexpr double MIN_RANGE_KM     = 1e-3;

}  // namespace

double phaseAngleRad(const Vec3& satEci, const Vec3& sunEci, const Vec3& siteEci) {
    const Vec3 toSun = (sunEci - satEci).unit();
    const Vec3 toObs = (siteEci - satEci).unit();

    if (toSun.norm() <= 0.0 || toObs.norm() <= 0.0) return PI / 2.0;

    double c = toSun.dot(toObs);
    if (c > 1.0) c = 1.0;
    if (c < -1.0) c = -1.0;

    return std::acos(c);
}

double apparentMagnitude(double stdMag, double rangeKm, double phaseRad) {
    if (phaseRad < 0.0) phaseRad = 0.0;
    if (phaseRad > PI)  phaseRad = PI;

    double phaseFactor = (PI - phaseRad) * std::cos(phaseRad) + std::sin(phaseRad);
    if (phaseFactor < MIN_PHASE_FACTOR) phaseFactor = MIN_PHASE_FACTOR;

    double range = rangeKm;
    if (range < MIN_RANGE_KM) range = MIN_RANGE_KM;

    return stdMag
         + 5.0 * std::log10(range / 1000.0)
         - 2.5 * std::log10(phaseFactor);
}
```

- [ ] **Step 4: Source the standard magnitude table**

Attempt to obtain the McCants/Molczan standard magnitude file (spec §13 item 3). It is distributed alongside the SeeSat-L community tooling; search for `quicksat.mag` or Molczan's `mcnames`/magnitude file.

Record what you found in `docs/third-party/STDMAG-PROVENANCE.md`:

```markdown
# Standard magnitude table — provenance

- **Source URL:** <the exact URL, or "not obtained">
- **Date retrieved:** <YYYY-MM-DD>
- **Licence / usage terms as stated:** <copy verbatim, or "unstated">
- **Coverage:** <how many NORAD ids were imported>

## Default for unknown objects

`DEFAULT_STD_MAG = 2.5`.

Rationale: the only objects reaching `stdMagFor` are members of CelesTrak's
`visual` group, which is *defined* as objects visible to the naked eye. A
mid-range value is therefore a defensible prior for an unlisted member, where a
faint default (+5) would hide the entire group and a bright one (-2) would
promise passes that are not there.

This is spec §13 item 3. If no licensed source is available, the seed table
below stands and the default carries the rest.
```

**Gate:** if licensing is unclear, **do not import the file.** Ship the seed table below and say so in the provenance document. This is not a blocker for M2 — the default covers the rest.

- [ ] **Step 5: Write the table**

Create `lib/core/src/StdMagTable.h`:

```cpp
#pragma once

// Standard magnitude: apparent visual magnitude at 1000 km range and 90 degrees
// phase angle. See docs/third-party/STDMAG-PROVENANCE.md for sourcing and for
// the reasoning behind the default.
constexpr double DEFAULT_STD_MAG = 2.5;

double stdMagFor(int noradId);
```

Create `lib/core/src/StdMagTable.cpp`:

```cpp
#include "StdMagTable.h"

#include <cstddef>

namespace {

struct Entry {
    int    norad;
    double stdMag;
};

// Seed table of widely published values for objects that dominate the visual
// group. Extend from the McCants/Molczan file if licensing permitted; the
// default covers everything absent here.
constexpr Entry TABLE[] = {
    { 25544, -1.8 },   // ISS (ZARYA)
    { 48274, -1.0 },   // CSS (TIANHE) - Chinese space station core
    { 20580,  2.0 },   // Hubble Space Telescope
    { 27386,  3.5 },   // Envisat
    { 25861,  3.0 },   // Okean O
    { 23405,  2.5 },   // SL-16 rocket body
};

}  // namespace

double stdMagFor(int noradId) {
    for (std::size_t i = 0; i < sizeof(TABLE) / sizeof(TABLE[0]); ++i) {
        if (TABLE[i].norad == noradId) return TABLE[i].stdMag;
    }
    return DEFAULT_STD_MAG;
}
```

- [ ] **Step 6: Run the test to verify it passes**

```bash
pio test -e native -f test_magnitude
```

Expected: PASS — 12 tests, 0 failures.

If `test_at_reference_conditions_returns_std_mag` fails, the formula has picked up a stray constant (the `−15.75` form uses a different phase-factor normalisation and is not interchangeable with this one). Fix the formula, never the test.

- [ ] **Step 7: Commit**

```bash
git add lib/core/src/Magnitude.h lib/core/src/Magnitude.cpp \
        lib/core/src/StdMagTable.h lib/core/src/StdMagTable.cpp \
        test/test_magnitude docs/third-party/STDMAG-PROVENANCE.md
git commit -m "feat(core): add phase angle, apparent magnitude and standard magnitude table"
```

---

## Task 4: The visibility verdict

Combines the four conditions into one answer, with a machine-readable reason. The reason string is what makes the difference between "the radar shows nothing" and "the radar shows nothing because it is daylight" when you are debugging at 2 a.m.

**Files:**
- Create: `lib/core/src/Visibility.h`, `lib/core/src/Visibility.cpp`
- Test: `test/test_visibility/test_visibility.cpp`

**Interfaces:**
- Consumes: `LookAngles` (M1 Task 5), `isSunlit` (Task 2), `apparentMagnitude`, `phaseAngleRad` (Task 3)
- Produces:
  - `enum class VisReason { Visible, BelowHorizon, Daylight, Eclipsed, TooDim }`
  - `struct Verdict { bool visible; double magnitude; VisReason reason; }`
  - `constexpr double MIN_ELEVATION_DEG = 10.0`, `MAX_SUN_ALT_DEG = -6.0`, `FAINTEST_VISIBLE_MAG = 4.5`
  - `Verdict judge(const LookAngles&, const Vec3& satEci, const Vec3& sunEci, const Vec3& siteEci, double sunAltDeg, double stdMag)`
  - `const char* visReasonName(VisReason)`

- [ ] **Step 1: Write the failing test**

Create `test/test_visibility/test_visibility.cpp`:

```cpp
#include <unity.h>
#include <cstring>
#include "Visibility.h"

// A geometry that satisfies every condition, used as the baseline that each
// test then breaks in exactly one way.
static const Vec3 SUN {1.496e8, 0.0, 0.0};
static const Vec3 SITE{-6378.0, 0.0, 0.0};      // night side, facing away
static const Vec3 SAT {-6778.0, 7000.0, 0.0};   // above the site, outside shadow
// The y component must exceed EARTH_RADIUS_KM (6378.137): perpendicular distance
// from the Earth-Sun axis is what decides the cylindrical shadow test, and this
// point is on the anti-sun side. y=3000 would be 3378 km INSIDE the shadow.

static LookAngles goodLook(void) {
    LookAngles la;
    la.azDeg = 142.0;
    la.elDeg = 45.0;
    la.rangeKm = 800.0;
    return la;
}

void test_all_conditions_met_is_visible(void) {
    Verdict v = judge(goodLook(), SAT, SUN, SITE, -14.0, -1.8);
    TEST_ASSERT_TRUE(v.visible);
    TEST_ASSERT_EQUAL_INT(static_cast<int>(VisReason::Visible),
                          static_cast<int>(v.reason));
}

void test_below_the_elevation_floor_is_rejected(void) {
    LookAngles la = goodLook();
    la.elDeg = 9.9;   // just under MIN_ELEVATION_DEG
    Verdict v = judge(la, SAT, SUN, SITE, -14.0, -1.8);
    TEST_ASSERT_FALSE(v.visible);
    TEST_ASSERT_EQUAL_INT(static_cast<int>(VisReason::BelowHorizon),
                          static_cast<int>(v.reason));
}

void test_exactly_at_the_elevation_floor_is_rejected(void) {
    LookAngles la = goodLook();
    la.elDeg = MIN_ELEVATION_DEG;
    TEST_ASSERT_FALSE(judge(la, SAT, SUN, SITE, -14.0, -1.8).visible);
}

void test_daylight_is_rejected(void) {
    Verdict v = judge(goodLook(), SAT, SUN, SITE, -5.9, -1.8);
    TEST_ASSERT_FALSE(v.visible);
    TEST_ASSERT_EQUAL_INT(static_cast<int>(VisReason::Daylight),
                          static_cast<int>(v.reason));
}

void test_civil_twilight_boundary_is_rejected(void) {
    TEST_ASSERT_FALSE(judge(goodLook(), SAT, SUN, SITE,
                            MAX_SUN_ALT_DEG, -1.8).visible);
}

void test_eclipsed_satellite_is_rejected(void) {
    Vec3 shadowed{-6778.0, 0.0, 0.0};   // squarely in the shadow cylinder
    Verdict v = judge(goodLook(), shadowed, SUN, SITE, -14.0, -1.8);
    TEST_ASSERT_FALSE(v.visible);
    TEST_ASSERT_EQUAL_INT(static_cast<int>(VisReason::Eclipsed),
                          static_cast<int>(v.reason));
}

void test_too_dim_is_rejected(void) {
    Verdict v = judge(goodLook(), SAT, SUN, SITE, -14.0, 9.0);
    TEST_ASSERT_FALSE(v.visible);
    TEST_ASSERT_EQUAL_INT(static_cast<int>(VisReason::TooDim),
                          static_cast<int>(v.reason));
}

void test_magnitude_is_reported_even_when_rejected(void) {
    // The renderer sizes blips by magnitude regardless of visibility, so the
    // number must be filled in on every path that got far enough to compute it.
    Verdict v = judge(goodLook(), SAT, SUN, SITE, -14.0, 9.0);
    TEST_ASSERT_TRUE(v.magnitude > 4.5);
    TEST_ASSERT_TRUE(v.magnitude < 30.0);
}

void test_horizon_check_precedes_everything(void) {
    // An object below the floor in daylight and eclipsed reports BelowHorizon,
    // so the reason is stable and does not depend on evaluation order.
    LookAngles la = goodLook();
    la.elDeg = -30.0;
    Vec3 shadowed{-6778.0, 0.0, 0.0};
    Verdict v = judge(la, shadowed, SUN, SITE, 30.0, -1.8);
    TEST_ASSERT_EQUAL_INT(static_cast<int>(VisReason::BelowHorizon),
                          static_cast<int>(v.reason));
}

void test_reason_names_are_stable(void) {
    TEST_ASSERT_EQUAL_STRING("visible",       visReasonName(VisReason::Visible));
    TEST_ASSERT_EQUAL_STRING("below_horizon", visReasonName(VisReason::BelowHorizon));
    TEST_ASSERT_EQUAL_STRING("daylight",      visReasonName(VisReason::Daylight));
    TEST_ASSERT_EQUAL_STRING("eclipsed",      visReasonName(VisReason::Eclipsed));
    TEST_ASSERT_EQUAL_STRING("too_dim",       visReasonName(VisReason::TooDim));
}

int main(int, char**) {
    UNITY_BEGIN();
    RUN_TEST(test_all_conditions_met_is_visible);
    RUN_TEST(test_below_the_elevation_floor_is_rejected);
    RUN_TEST(test_exactly_at_the_elevation_floor_is_rejected);
    RUN_TEST(test_daylight_is_rejected);
    RUN_TEST(test_civil_twilight_boundary_is_rejected);
    RUN_TEST(test_eclipsed_satellite_is_rejected);
    RUN_TEST(test_too_dim_is_rejected);
    RUN_TEST(test_magnitude_is_reported_even_when_rejected);
    RUN_TEST(test_horizon_check_precedes_everything);
    RUN_TEST(test_reason_names_are_stable);
    return UNITY_END();
}
```

- [ ] **Step 2: Run the test to verify it fails**

```bash
pio test -e native -f test_visibility
```

Expected: FAIL — `fatal error: Visibility.h: No such file or directory`.

- [ ] **Step 3: Write the minimal implementation**

Create `lib/core/src/Visibility.h`:

```cpp
#pragma once

#include "Topocentric.h"
#include "Vec3.h"

// Spec section 5 thresholds. All four conditions must hold.
constexpr double MIN_ELEVATION_DEG    = 10.0;   // atmospheric extinction floor
constexpr double MAX_SUN_ALT_DEG      = -6.0;   // end of civil twilight
constexpr double FAINTEST_VISIBLE_MAG = 4.5;    // naked eye, suburban sky

enum class VisReason {
    Visible,
    BelowHorizon,
    Daylight,
    Eclipsed,
    TooDim
};

struct Verdict {
    bool      visible   = false;
    double    magnitude = 99.0;
    VisReason reason    = VisReason::BelowHorizon;
};

// Conditions are evaluated in a fixed order - horizon, then darkness, then
// illumination, then brightness - so the reason is deterministic.
Verdict judge(const LookAngles& la,
              const Vec3& satEci,
              const Vec3& sunEci,
              const Vec3& siteEci,
              double sunAltDeg,
              double stdMag);

const char* visReasonName(VisReason r);
```

Create `lib/core/src/Visibility.cpp`:

```cpp
#include "Visibility.h"

#include "Eclipse.h"
#include "Magnitude.h"

const char* visReasonName(VisReason r) {
    switch (r) {
        case VisReason::Visible:      return "visible";
        case VisReason::BelowHorizon: return "below_horizon";
        case VisReason::Daylight:     return "daylight";
        case VisReason::Eclipsed:     return "eclipsed";
        case VisReason::TooDim:       return "too_dim";
    }
    return "below_horizon";
}

Verdict judge(const LookAngles& la,
              const Vec3& satEci,
              const Vec3& sunEci,
              const Vec3& siteEci,
              double sunAltDeg,
              double stdMag) {
    Verdict v;

    if (la.elDeg <= MIN_ELEVATION_DEG) {
        v.reason = VisReason::BelowHorizon;
        return v;
    }

    if (sunAltDeg >= MAX_SUN_ALT_DEG) {
        v.reason = VisReason::Daylight;
        return v;
    }

    if (!isSunlit(satEci, sunEci)) {
        v.reason = VisReason::Eclipsed;
        return v;
    }

    // Brightness is computed last because it is the only expensive condition,
    // and it is reported even on the TooDim path so the renderer can still size
    // the blip.
    const double phi = phaseAngleRad(satEci, sunEci, siteEci);
    v.magnitude = apparentMagnitude(stdMag, la.rangeKm, phi);

    if (v.magnitude > FAINTEST_VISIBLE_MAG) {
        v.reason = VisReason::TooDim;
        return v;
    }

    v.visible = true;
    v.reason  = VisReason::Visible;
    return v;
}
```

- [ ] **Step 4: Run the test to verify it passes**

```bash
pio test -e native -f test_visibility
```

Expected: PASS — 10 tests, 0 failures.

- [ ] **Step 5: Commit**

```bash
git add lib/core/src/Visibility.h lib/core/src/Visibility.cpp test/test_visibility
git commit -m "feat(core): add four-condition visibility verdict with reasons"
```

---
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

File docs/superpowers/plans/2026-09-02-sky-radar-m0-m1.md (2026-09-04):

# Sky Radar M0–M1 Implementation Plan

> **For agentic workers:** REQUIRED SUB-SKILL: Use superpowers:subagent-driven-development (recommended) or superpowers:executing-plans to implement this plan task-by-task. Steps use checkbox (`- [ ]`) syntax for tracking.

**Goal:** A standalone ESP32-S3 that fetches ISS and Tiangong orbital elements, propagates them on-device, and serves a 240×240 circular radar to a browser showing both objects moving across the sky in real time.

**Architecture:** A platform-free C++ core (`lib/core/`) owns all orbital maths and produces a *snapshot* of normalised polar blips. Firmware (`src/`) owns WiFi, NTP, HTTPS fetching, LittleFS caching, and an HTTP server. The browser is a dumb polar plotter that draws whatever the snapshot says. The core compiles and is unit-tested natively on a PC, so no orbital maths is ever debugged through a flash cycle.

**Tech Stack:** PlatformIO (two environments: `esp32-s3-devkitc-1` and `native`), Arduino-ESP32 framework, Unity test framework, vendored SGP4 (dnwrnr/sgp4, Apache-2.0), LittleFS, vanilla JS + Canvas 2D. **No third-party runtime libraries.**

## Global Constraints

Copied from `docs/superpowers/specs/2026-09-02-esp32-sky-radar-design.md`:

- **Board:** ESP32-S3-DevKitC-1 **N16R8** — 16 MB flash, 8 MB octal PSRAM. Requires `board_build.arduino.memory_type = qio_opi`.
- **Projection happens in the core; renderers are dumb polar plotters.** No renderer contains orbital geometry. Renderers receive `r` (0..1) and `theta` (degrees, sky frame, 0 = true north).
- **`lib/core/` must not include any Arduino or ESP-IDF header.** It compiles under `platform = native`. This is enforced by the native test build succeeding.
- **Rotation to physical orientation is applied by the renderer at draw time** from `HeadingSource`. The core always emits sky-frame `theta`.
- **If NTP has never succeeded, refuse to propagate.** Emit `status: "no_time"` and no blips. Never plot from an unknown clock.
- **TLS: use `setCACertBundle` / `esp_crt_bundle`.** Never `setInsecure()`. Never pin a single root certificate.
- **HTTPS fetches are serialised, short-lived and fully torn down.** Never two concurrently; never held open between fetches.
- **Palette (deep-red instrument):** background `#060305`, dim grid `#3a1210`, mid grid `#5a1c17`, visibility-floor ring `#6b241d`, text `#c9503c`, sweep `rgba(201,80,60,0.10)`. **`#d8f4ff` is reserved exclusively for "visible right now"** and must not be used for chrome.
- **Viewport:** 240×240 logical, circular, displayed at 3× with `image-rendering: pixelated`. No hover, no tooltips, no mouse input. Text budget ≈ 20 characters on the bottom arc.
- **Blip cap:** the core ranks and truncates to ≤ 12 blips. Renderers never decide what matters. (Ranking is trivial at M1 with 2 objects; the cap and the ordering hook must still exist.)
- **Commit after every task.** Never `git push`, never create a remote, never open a PR.

### Spec amendment proposed by this plan

The spec (§3.3) says the browser consumes the snapshot **over WebSocket**. This plan uses **1 Hz HTTP polling of `GET /api/scope`** instead.

Rationale: the snapshot is under 2 KB, 1 Hz is well inside what polling handles, and the async-webserver libraries that WebSockets require on ESP32 (AsyncTCP) have a long history of heap-corruption crashes. Polling uses the `WebServer` class already in the Arduino-ESP32 core, adding **zero third-party dependencies**. Transport is invisible to the LCD renderer, so nothing downstream is affected. If push ever becomes necessary, Server-Sent Events over the same synchronous server is the next step, not WebSockets.

---

## File Structure

```
platformio.ini              two envs: esp32-s3-devkitc-1, native
lib/core/src/
  Vec3.h                    3-vector maths (header-only)
  TimeUtils.h/.cpp          unix -> Julian date, GMST
  Tle.h/.cpp                TLE parsing, checksum, COSPAR designator
  sgp4/                     vendored dnwrnr/sgp4 (Apache-2.0)
  Propagator.h/.cpp         Tle -> TEME position at a unix time
  Observer.h                observer site definition (header-only struct)
  Topocentric.h/.cpp        site ECI vector; sat + site -> az/el/range
  Projection.h/.cpp         az/el -> normalised (r, theta)
  Snapshot.h/.cpp           Blip/Snapshot structs, ranking, JSON serialisation
src/
  main.cpp                  setup/loop, orchestration
  Config.h/.cpp             observer position in NVS
  Net.h/.cpp                WiFi association + NTP, time-validity flag
  TleStore.h/.cpp           LittleFS TLE cache with fetch timestamp
  TleFetcher.h/.cpp         streaming HTTPS TLE fetch from CelesTrak
  ScopeService.h/.cpp       owns Tles, builds Snapshot on demand
  HttpApi.h/.cpp            WebServer routes: static files + /api/scope
  secrets.h                 gitignored: WIFI_SSID, WIFI_PASS
data/
  index.html                page shell, 3x scaled canvas
  radar.js                  the polar plotter
  radar.css                 layout, pixelated scaling
test/
  test_vec3/test_vec3.cpp
  test_timeutils/test_timeutils.cpp
  test_tle/test_tle.cpp
  test_propagator/test_propagator.cpp
  test_topocentric/test_topocentric.cpp
  test_projection/test_projection.cpp
  test_snapshot/test_snapshot.cpp
```

**Why split this way:** every file under `lib/core/src/` is one pure transformation with a testable signature. Files under `src/` are grouped by the *resource* they own (network, filesystem, HTTP), not by layer, so a change to caching touches exactly one file.

---

## Task 1: Project scaffolding and the native test harness

Establishes both build environments and proves the native one can compile and test core code with no Arduino headers. `Vec3` is the vehicle — it is genuinely needed by later tasks and small enough to verify the harness in one cycle.

**Files:**
- Create: `platformio.ini`
- Create: `lib/core/src/Vec3.h`
- Test: `test/test_vec3/test_vec3.cpp`

**Interfaces:**
- Consumes: nothing
- Produces: `struct Vec3` with fields `double x, y, z`; methods `operator+`, `operator-`, `operator*(double)`, `dot(const Vec3&) -> double`, `norm() -> double`, `unit() -> Vec3`. `unit()` on a zero vector returns `{0,0,0}` rather than NaN.

- [ ] **Step 1: Create `platformio.ini`**

```ini
[platformio]
default_envs = esp32-s3-devkitc-1

[env:esp32-s3-devkitc-1]
platform = espressif32
board = esp32-s3-devkitc-1
framework = arduino
board_build.arduino.memory_type = qio_opi
board_build.flash_mode = qio
board_build.partitions = default_16MB.csv
board_build.filesystem = littlefs
board_upload.flash_size = 16MB
monitor_speed = 115200
build_flags =
    -std=gnu++17
    -DBOARD_HAS_PSRAM
    -DARDUINO_USB_CDC_ON_BOOT=1
build_unflags = -std=gnu++11
test_ignore = *

[env:native]
platform = native
test_framework = unity
build_src_filter = -<*>
build_flags =
    -std=gnu++17
    -I lib/core/src
    -D UNITY_INCLUDE_DOUBLE
```

`UNITY_INCLUDE_DOUBLE` is not optional. PlatformIO's bundled Unity targets embedded platforms and **excludes double-precision assertions by default**, so `TEST_ASSERT_DOUBLE_WITHIN` compiles fine and then fails at runtime with "Unity Double Precision Disabled". Every test in this plan and the M2 plan uses it.

`build_src_filter = -<*>` stops the native build from trying to compile `src/`, which contains Arduino code. `test_ignore = *` stops `pio test` from attempting to run the native suites on the board.

- [ ] **Step 2: Write the failing test**

Create `test/test_vec3/test_vec3.cpp`:

```cpp
#include <unity.h>
#include "Vec3.h"

void test_norm_of_345_triangle(void) {
    Vec3 v{3.0, 4.0, 0.0};
    TEST_ASSERT_DOUBLE_WITHIN(1e-12, 5.0, v.norm());
}

void test_dot_product(void) {
    Vec3 a{1.0, 2.0, 3.0};
    Vec3 b{4.0, -5.0, 6.0};
    TEST_ASSERT_DOUBLE_WITHIN(1e-12, 12.0, a.dot(b));
}

void test_subtraction(void) {
    Vec3 a{5.0, 5.0, 5.0};
    Vec3 b{1.0, 2.0, 3.0};
    Vec3 c = a - b;
    TEST_ASSERT_DOUBLE_WITHIN(1e-12, 4.0, c.x);
    TEST_ASSERT_DOUBLE_WITHIN(1e-12, 3.0, c.y);
    TEST_ASSERT_DOUBLE_WITHIN(1e-12, 2.0, c.z);
}

void test_unit_has_length_one(void) {
    Vec3 v{3.0, 4.0, 0.0};
    TEST_ASSERT_DOUBLE_WITHIN(1e-12, 1.0, v.unit().norm());
}

void test_unit_of_zero_vector_is_zero_not_nan(void) {
    Vec3 z{0.0, 0.0, 0.0};
    Vec3 u = z.unit();
    TEST_ASSERT_DOUBLE_WITHIN(1e-12, 0.0, u.x);
    TEST_ASSERT_DOUBLE_WITHIN(1e-12, 0.0, u.y);
    TEST_ASSERT_DOUBLE_WITHIN(1e-12, 0.0, u.z);
}

int main(int, char**) {
    UNITY_BEGIN();
    RUN_TEST(test_norm_of_345_triangle);
    RUN_TEST(test_dot_product);
    RUN_TEST(test_subtraction);
    RUN_TEST(test_unit_has_length_one);
    RUN_TEST(test_unit_of_zero_vector_is_zero_not_nan);
    return UNITY_END();
}
```

- [ ] **Step 3: Run the test to verify it fails**

```bash
pio test -e native
```

Expected: FAIL — `fatal error: Vec3.h: No such file or directory`.

- [ ] **Step 4: Write the minimal implementation**

Create `lib/core/src/Vec3.h`:

```cpp
#pragma once
#include <cmath>

struct Vec3 {
    double x = 0.0, y = 0.0, z = 0.0;

    Vec3() = default;
    Vec3(double x_, double y_, double z_) : x(x_), y(y_), z(z_) {}

    Vec3 operator+(const Vec3& o) const { return {x + o.x, y + o.y, z + o.z}; }
    Vec3 operator-(const Vec3& o) const { return {x - o.x, y - o.y, z - o.z}; }
    Vec3 operator*(double s) const { return {x * s, y * s, z * s}; }

    double dot(const Vec3& o) const { return x * o.x + y * o.y + z * o.z; }
    double norm() const { return std::sqrt(dot(*this)); }

    Vec3 unit() const {
        const double n = norm();
        if (n <= 0.0) return {0.0, 0.0, 0.0};
        return {x / n, y / n, z / n};
    }
};
```

- [ ] **Step 5: Run the test to verify it passes**

```bash
pio test -e native
```

Expected: PASS — 5 tests, 0 failures.

- [ ] **Step 6: Verify the firmware environment also builds**

```bash
pio run -e esp32-s3-devkitc-1
```

Expected: this will FAIL with "Nothing to build" or a missing-`src` error. Create a placeholder `src/main.cpp` so the environment is proven:

```cpp
#include <Arduino.h>

void setup() {
    Serial.begin(115200);
}

void loop() {
    delay(1000);
}
```

Re-run `pio run -e esp32-s3-devkitc-1`. Expected: SUCCESS.

- [ ] **Step 7: Commit**

```bash
git add platformio.ini lib/core/src/Vec3.h test/test_vec3/test_vec3.cpp src/main.cpp
git commit -m "build: scaffold PlatformIO envs and native test harness with Vec3"
```

---
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

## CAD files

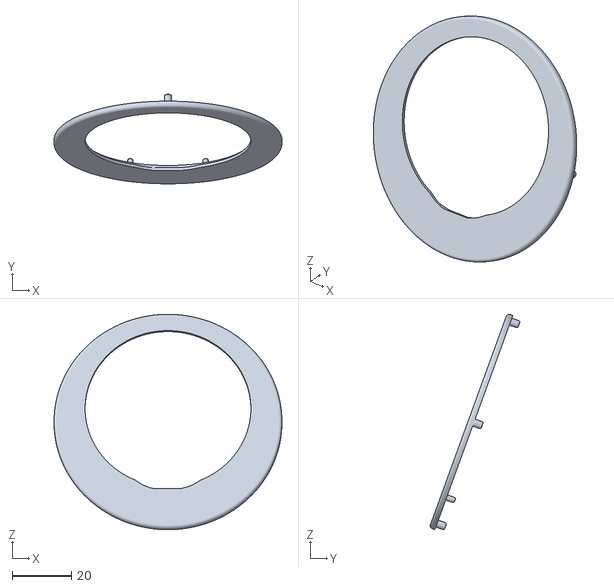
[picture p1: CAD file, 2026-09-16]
enclosure-front-lid.stl
77.0 x 30.3 x 72.7

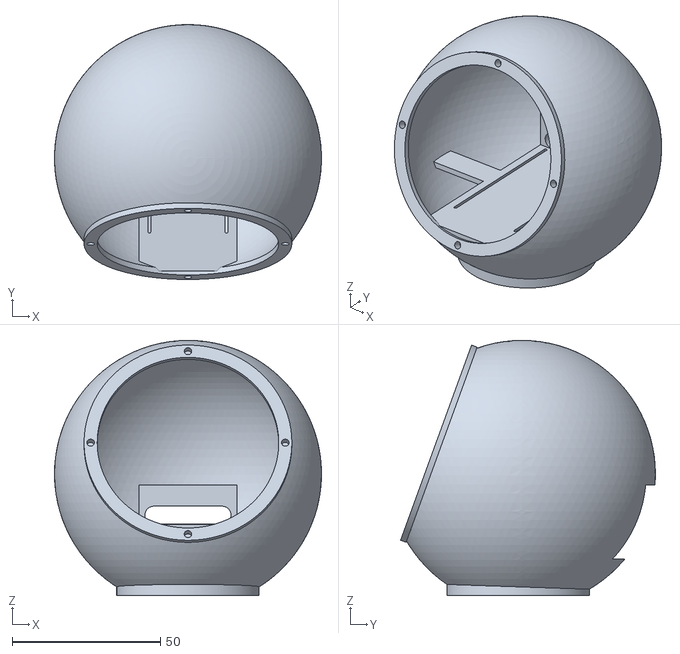
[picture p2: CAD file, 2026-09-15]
enclosure-Body.stl
90.0 x 85.9 x 86.0

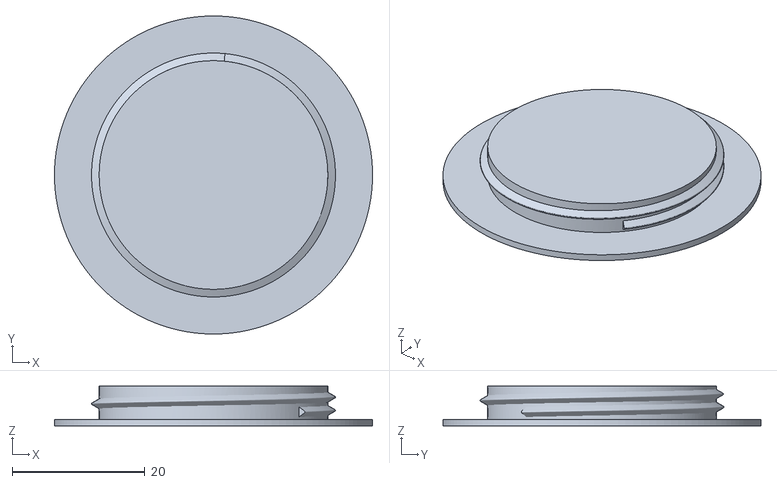
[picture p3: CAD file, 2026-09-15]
enclosure-bottom-screwcap.stl
48.0 x 48.0 x 6.00

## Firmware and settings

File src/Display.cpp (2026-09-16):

#define LGFX_USE_V1
#include "Display.h"

#include <Arduino.h>
#include <LovyanGFX.hpp>

#include <cmath>
#include <cstdio>

#include "Pins.h"

namespace display {

namespace {

// --- Panel wiring ---------------------------------------------------------

class SkyPanel : public lgfx::LGFX_Device {
    lgfx::Panel_GC9B72 _panel;
    lgfx::Bus_SPI      _bus;
    lgfx::Light_PWM    _light;

public:
    SkyPanel() {
        {
            auto cfg = _bus.config();
            cfg.spi_host   = SPI2_HOST;      // FSPI, whose native pins we use
            cfg.spi_mode   = 0;              // GC9B72 is mode 0
            // The panel's reference driver reports reliable operation to about
            // 20 MHz on jumper leads. Starting there rather than at the bus
            // maximum: a too-fast clock does not fail cleanly, it produces
            // intermittently corrupt pixels that look like a rendering bug.
            cfg.freq_write = 20000000;
            cfg.freq_read  = 8000000;
            cfg.spi_3wire  = false;
            cfg.use_lock   = true;
            cfg.dma_channel = SPI_DMA_CH_AUTO;
            cfg.pin_sclk   = PIN_TFT_SCLK;
            cfg.pin_mosi   = PIN_TFT_MOSI;
            cfg.pin_miso   = -1;             // SDO deliberately unconnected
            cfg.pin_dc     = PIN_TFT_DC;
            _bus.config(cfg);
            _panel.setBus(&_bus);
        }
        {
            auto cfg = _panel.config();
            cfg.pin_cs   = PIN_TFT_CS;
            cfg.pin_rst  = PIN_TFT_RST;
            cfg.pin_busy = -1;
            cfg.panel_width  = TFT_WIDTH_PX;
            cfg.panel_height = TFT_HEIGHT_PX;
            cfg.offset_x = 0;
            cfg.offset_y = 0;
            cfg.offset_rotation = 0;
            cfg.readable = false;            // no MISO wired
            // Both of these were wrong on the first bring-up, and the way they
            // were wrong is worth recording because one symptom identified two
            // faults.
            //
            // The panel came up with a white field and brownish-yellow lines.
            // A white background can only mean inversion is being applied when
            // it should not - the palette's background is #060305, and nothing
            // else turns that white. But inversion alone does not explain the
            // lines: the chrome colour #c9503c inverts to #36afc3, a pale cyan,
            // not brown. #c3af36 is that same cyan with its red and blue
            // channels exchanged, so the colour order was reversed as well.
            // Hence both flags flip, not just the obvious one.
            cfg.invert   = false;
            cfg.rgb_order = true;            // this panel is RGB, not BGR
            cfg.dlen_16bit = false;
            cfg.bus_shared = false;
            _panel.config(cfg);
        }
        {
            auto cfg = _light.config();
            cfg.pin_bl = PIN_TFT_BL;
            cfg.invert = false;
            cfg.freq   = 12000;
            cfg.pwm_channel = 7;
            _light.config(cfg);
            _panel.setLight(&_light);
        }
        setPanel(&_panel);
    }
};

SkyPanel      lcd;
lgfx::LGFX_Sprite canvas(&lcd);
bool g_present = false;

// --- Geometry -------------------------------------------------------------

constexpr int CX = TFT_WIDTH_PX / 2;
constexpr int CY = TFT_HEIGHT_PX / 2;
constexpr int RR = (TFT_WIDTH_PX / 2) - 2;   // 2 px of margin so nothing clips

// --- Palette --------------------------------------------------------------
//
// The same deep-red instrument palette as data/radar.js. #d8f4ff stays
// reserved exclusively for "satellite visible right now" and must never be
// used for chrome.

inline uint16_t rgb(uint8_t r, uint8_t g, uint8_t b) { return lgfx::color565(r, g, b); }

const uint16_t C_BG        = rgb(0x06, 0x03, 0x05);
const uint16_t C_GRID_DIM  = rgb(0x3a, 0x12, 0x10);
const uint16_t C_GRID_MID  = rgb(0x5a, 0x1c, 0x17);
const uint16_t C_FLOOR     = rgb(0x6b, 0x24, 0x1d);
const uint16_t C_TEXT      = rgb(0xc9, 0x50, 0x3c);
const uint16_t C_VISIBLE   = rgb(0xd8, 0xf4, 0xff);
const uint16_t C_SWEEP     = rgb(0x1a, 0x0a, 0x09);
const uint16_t C_RADIANT   = rgb(0xe0, 0x29, 0x3f);
const uint16_t C_RADIANT_P = rgb(0xff, 0x6b, 0x57);
const uint16_t C_NEO       = rgb(0xc9, 0x50, 0x3c);
const uint16_t C_NEO_CLOSE = rgb(0xff, 0x6b, 0x57);
const uint16_t C_NEO_MOON  = rgb(0x8a, 0x2f, 0x26);

// --- Backlight ------------------------------------------------------------
//
// A ladder rather than a linear step: perceived brightness is roughly
// logarithmic, so a fixed increment is invisible at the top and slams to black
// at the bottom. The lowest rung is genuinely dim - this thing sits in a dark
// room and the whole red palette exists to protect dark adaptation.
const uint8_t BRIGHTNESS_LADDER[] = {8, 20, 45, 90, 160, 255};
constexpr int LADDER_LEN = sizeof(BRIGHTNESS_LADDER) / sizeof(BRIGHTNESS_LADDER[0]);
int g_rung = 2;   // 45/255

// Idle dim. Gestures are the only input, so an instrument left alone all night
// should not sit at full brightness.
constexpr uint32_t IDLE_DIM_AFTER_MS = 10UL * 60UL * 1000UL;
constexpr uint8_t  IDLE_LEVEL = 6;
uint32_t g_lastWakeMs = 0;
bool     g_dimmed     = false;

constexpr uint32_t FRAME_INTERVAL_MS = 100;   // 10 Hz
uint32_t g_lastFrameMs = 0;
double   g_sweepDeg    = 0.0;

// --- Helpers --------------------------------------------------------------

void polar(double r, double thetaDeg, int& x, int& y) {
    const double a = (thetaDeg - 90.0) * M_PI / 180.0;
    x = CX + static_cast<int>(lround(r * RR * cos(a)));
    y = CY + static_cast<int>(lround(r * RR * sin(a)));
}

uint16_t ringColour(const std::string& kind) {
    if (kind == "floor")   return C_FLOOR;
    if (kind == "horizon") return C_GRID_MID;
    if (kind == "moon")    return C_NEO_MOON;
    return C_GRID_DIM;
}

bool isNeo(const Snapshot& s) { return s.mode == ScopeMode::Neo; }

// Blip radius from apparent magnitude - brighter draws bigger. Same clamp as
// the web renderer, scaled 1.5x for the larger panel.
int blipRadius(double mag) {
    if (!std::isfinite(mag)) return 3;
    double px = 4.8 - mag * 0.68;
    if (px < 2.0) px = 2.0;
    if (px > 7.0) px = 7.0;
    return static_cast<int>(lround(px));
}

int neoRadius(double diameterM) {
    if (!std::isfinite(diameterM) || diameterM <= 0.0) return 3;
    double px = 1.8 + log10(diameterM) * 2.0;
    if (px < 3.0) px = 3.0;
    if (px > 9.0) px = 9.0;
    return static_cast<int>(lround(px));
}

void drawChrome(const Snapshot& s) {
    canvas.fillScreen(C_BG);

    for (const Ring& rg : s.rings) {
        canvas.drawCircle(CX, CY, static_cast<int>(lround(rg.r * RR)), ringColour(rg.kind));
    }

    // Radial ticks every 30 degrees.
    for (int th = 0; th < 360; th += 30) {
        int x1, y1, x2, y2;
        polar(0.955, th, x1, y1);
        polar(1.0, th, x2, y2);
        canvas.drawLine(x1, y1, x2, y2, C_GRID_DIM);
    }

    canvas.setFont(&fonts::Font2);
    canvas.setTextDatum(middle_center);
    canvas.setTextColor(C_TEXT, C_BG);

    if (isNeo(s)) {
        // The angular axis is time here, not azimuth.
        const int days = 30;
        char buf[8];
        const int marks[4] = {0, 90, 180, 270};
        for (int i = 0; i < 4; ++i) {
            int x, y;
            polar(0.90, marks[i], x, y);
            if (i == 0) {
                canvas.drawString("NOW", x, y);
            } else {
                // Rounded, not truncated: a quarter of 30 days is 7.5, and
                // integer division would label it "+7D" here while the web
                // renderer rounds to "+8D". Same dial, same snapshot, two
                // different numbers - exactly the drift the shared projection
                // exists to prevent.
                const int d = static_cast<int>(lround(days * i / 4.0));
                std::snprintf(buf, sizeof(buf), "+%dD", d);
                canvas.drawString(buf, x, y);
            }
        }
    } else {
        const char* names[4] = {"N", "E", "S", "W"};
        const int   angs[4]  = {0, 90, 180, 270};
        for (int i = 0; i < 4; ++i) {
            int x, y;
            polar(0.90, angs[i], x, y);
            canvas.drawString(names[i], x, y);
        }
    }

    // Ring labels. Only NEO mode sends them, because only there does the radius
    // mean something other than an elevation. The innermost goes on the
    // opposite diagonal and slightly outside its own ring: on a 10 LD dial the
    // 1 LD ring is a tenth of the radius, so its label would otherwise land on
    // top of the Earth marker.
    canvas.setFont(&fonts::Font0);
    for (const Ring& rg : s.rings) {
        if (rg.label.empty()) continue;
        const bool moon = (rg.kind == "moon");
        const double rl = moon ? rg.r + 0.07 : std::fmin(rg.r, 0.93);
        int x, y;
        polar(rl, moon ? 135.0 : 225.0, x, y);
        canvas.setTextColor(moon ? C_NEO_CLOSE : C_TEXT, C_BG);
        canvas.drawString(rg.label.c_str(), x, y);
    }
}

void drawSweep() {
    // LovyanGFX measures arc angles from 3 o'clock, clockwise; the dial's
    // theta is measured from north. Hence the -90.
    const float a1 = static_cast<float>(g_sweepDeg - 90.0);
    canvas.fillArc(CX, CY, 0, RR, a1 - 32.0f, a1, C_SWEEP);
}

void drawRadiants(const Snapshot& s) {
    for (const Radiant& rad : s.radiants) {
        int x, y;
        polar(rad.r, rad.theta, x, y);
        int radius = 9 + static_cast<int>(rad.zhr * 0.12);
        if (radius > 30) radius = 30;

        // A radiant is a region of sky to watch, not an object to point at, so
        // it is drawn as a soft patch rather than a hard dot. Concentric rings
        // approximate the web view's radial gradient, which the panel has no
        // alpha channel for.
        const uint16_t c = rad.atPeak ? C_RADIANT_P : C_RADIANT;
        for (int k = radius; k > 0; k -= 3) {
            canvas.drawCircle(x, y, k, c);
        }
    }
}

void drawBlips(const Snapshot& s) {
    for (const Blip& b : s.blips) {
        // Trail first, so the object always reads on top of its own history.
        for (const auto& t : b.trail) {
            int tx, ty;
            polar(t.first, t.second, tx, ty);
            canvas.fillCircle(tx, ty, 1, C_GRID_MID);
        }

        int x, y;
        polar(b.r, b.theta, x, y);
        const uint16_t c = b.visible ? C_VISIBLE : C_TEXT;
        canvas.fillCircle(x, y, blipRadius(b.magnitude), c);

        // Train members fly in formation; a ring around them says "this is one
        // of a group" without needing a connector the panel has no room for.
        if (b.kind == "train") {
            canvas.drawCircle(x, y, blipRadius(b.magnitude) + 3, C_FLOOR);
        }
    }
}

void drawNeos(const Snapshot& s) {
    // Earth at the centre - every radius on this dial is measured from it.
    canvas.fillCircle(CX, CY, 5, C_GRID_MID);

    // The "now" hand. Fixed, not sweeping: a sweep would imply the dial is
    // scanning something live, when it is a 30-day forecast.
    int nx, ny;
    polar(1.0, 0.0, nx, ny);
    canvas.drawLine(CX, CY, nx, ny, C_FLOOR);

    for (const NeoApproachBlip& n : s.neos) {
        int x, y;
        polar(n.r, n.theta, x, y);
        const bool close = n.distLd < 1.0;
        const int  rad   = neoRadius(n.estimatedDiameterM);

        if (close) {
            // Inside the Moon's distance is the one case worth drawing
            // attention to.
            canvas.drawCircle(x, y, rad + 4, C_NEO_CLOSE);
            canvas.drawCircle(x, y, rad + 7, C_NEO_CLOSE);
        }
        canvas.fillCircle(x, y, rad, close ? C_NEO_CLOSE : C_NEO);
    }
}

void statusLine(const Snapshot& s, char* out, size_t n) {
    switch (s.status) {
        case ScopeStatus::NoTime:
            std::snprintf(out, n, "NO TIME");
            return;
        case ScopeStatus::NoLocation:
            // NEO mode is Earth-centred and works without a location, so only
            // SKY mode nags about setup.
            if (!isNeo(s)) { std::snprintf(out, n, "SET LOCATION"); return; }
            break;
        default: break;
    }

    if (isNeo(s)) {
        if (s.neos.empty()) { std::snprintf(out, n, "NO CLOSE PASSES"); return; }
        const NeoApproachBlip& a = s.neos[0];   // sorted by date
        const long days = static_cast<long>(a.approachIn / 86400);
        if (days >= 1) {
            std::snprintf(out, n, "%s %ldD %.1fLD", a.name.c_str(), days, a.distLd);
        } else {
            std::snprintf(out, n, "%s %ldH %.1fLD", a.name.c_str(),
                          static_cast<long>(a.approachIn / 3600), a.distLd);
        }
        return;
    }

    // A pending visible pass outranks the current-position readout.
    if (!s.events.empty()) {
        const Event& e = s.events[0];
        const long mins = e.startsIn / 60 < 0 ? 0 : static_cast<long>(e.startsIn / 60);
        if (mins >= 60) {
            std::snprintf(out, n, "%s %ldH %.0f", e.name.c_str(), mins / 60, e.maxEl);
        } else {
            std::snprintf(out, n, "%s %ldM %.0f", e.name.c_str(), mins, e.maxEl);
        }
        return;
    }

    if (s.status == ScopeStatus::Offline) { std::snprintf(out, n, "OFFLINE"); return; }
    if (s.blips.empty())                  { std::snprintf(out, n, "NOTHING UP"); return; }

    const Blip& b = s.blips[0];
    std::snprintf(out, n, "%s %.0fDEG", b.name.c_str(), b.elevationDeg);
}

void drawStatus(const Snapshot& s) {
    char line[48];
    statusLine(s, line, sizeof(line));

    canvas.setFont(&fonts::Font2);
    canvas.setTextDatum(middle_center);
    canvas.setTextColor(C_TEXT, C_BG);
    canvas.drawString(line, CX, CY + static_cast<int>(RR * 0.62));

    if (isNeo(s)) {
        canvas.drawString("NEO", CX, CY - static_cast<int>(RR * 0.70));
    } else if (s.tleAgeHours >= 0.0) {
        char age[16];
        std::snprintf(age, sizeof(age), "TLE %.0fH", s.tleAgeHours);
        canvas.drawString(age, CX, CY - static_cast<int>(RR * 0.70));
    }
}

}  // namespace

bool begin() {
    if (!lcd.init()) {
        Serial.println("[display] GC9B72 init failed - running headless");
        g_present = false;
        return false;
    }
    lcd.setRotation(0);
    lcd.fillScreen(C_BG);

    // 360x360 at 16bpp is 253 KB, which will not fit in internal RAM alongside
    // WiFi and ~200 tracked objects. It goes to PSRAM, where 8 MB is sitting
    // almost unused. Drawing offscreen and pushing once is also what keeps the
    // sweep from tearing.
    canvas.setColorDepth(16);
    canvas.setPsram(true);
    if (!canvas.createSprite(TFT_WIDTH_PX, TFT_HEIGHT_PX)) {
        Serial.println("[display] could not allocate the 360x360 PSRAM canvas");
        g_present = false;
        return false;
    }

    g_present    = true;
    g_lastWakeMs = millis();
    setBrightness(BRIGHTNESS_LADDER[g_rung]);
    Serial.printf("[display] GC9B72 %dx%d ready, canvas in PSRAM (%u bytes free)\n",
                  TFT_WIDTH_PX, TFT_HEIGHT_PX,
                  static_cast<unsigned>(ESP.getFreePsram()));
    return true;
}

bool present() { return g_present; }

void setBrightness(uint8_t level) {
    if (!g_present) return;
    lcd.setBrightness(level);
}

uint8_t brightness() { return BRIGHTNESS_LADDER[g_rung]; }

void nudgeBrightness(int steps) {
    g_rung += steps;
    if (g_rung < 0) g_rung = 0;
    if (g_rung >= LADDER_LEN) g_rung = LADDER_LEN - 1;
    g_dimmed     = false;
    g_lastWakeMs = millis();
    setBrightness(BRIGHTNESS_LADDER[g_rung]);
    Serial.printf("[display] brightness %u/255\n",
                  static_cast<unsigned>(BRIGHTNESS_LADDER[g_rung]));
}

void wake() {
    g_dimmed     = false;
    g_lastWakeMs = millis();
    setBrightness(BRIGHTNESS_LADDER[g_rung]);
}

void loop(const Snapshot& s) {
    if (!g_present) return;

    if (!g_dimmed && (millis() - g_lastWakeMs) > IDLE_DIM_AFTER_MS) {
        g_dimmed = true;
        setBrightness(IDLE_LEVEL);
    }

    if (millis() - g_lastFrameMs < FRAME_INTERVAL_MS) return;
    g_lastFrameMs = millis();

    g_sweepDeg = std::fmod(g_sweepDeg + 4.0, 360.0);

    drawChrome(s);
    if (isNeo(s)) {
        drawNeos(s);
    } else {
        drawSweep();
        drawRadiants(s);
        drawBlips(s);
    }
    drawStatus(s);

    canvas.pushSprite(0, 0);
}

}  // namespace display

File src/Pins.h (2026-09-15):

#pragma once

// Single source of truth for how this instrument is wired (M6).
//
// Board: ESP32-S3-DevKitC-1 clone, ESP32-S3-WROOM-1 N16R8 module.
//
// PINS THAT MUST NEVER BE USED ON THIS MODULE:
//   26 - 32   SPI flash
//   33 - 37   octal PSRAM. Broken out on the header and therefore a trap -
//             35/36/37 sit in the middle of the pin row and driving any of
//             them crashes the chip.
//   19, 20    native USB D-/D+
//   43, 44    UART0, the serial console this project debugs over
//   0         BOOT button / strapping
//   45, 46    strapping pins, sampled at reset
//
// Everything below is drawn from what is left.

// --- Display: GC9B72, 2.1", 360x360, 4-wire SPI -------------------------
//
// 3.3 V ONLY. The panel's reference driver is explicit that 5 V on VCC
// destroys it, and there is no regulator on the breakout.
//
// CS/MOSI/SCLK are the ESP32-S3's native FSPI pins, which keeps the transfer
// on the dedicated IO mux instead of routing through the GPIO matrix, so the
// panel can be clocked as fast as the wiring allows. Keep these leads short -
// the panel is good for roughly 20 MHz on jumper wires, less if they are long.
//
// SDO (read-back) and TE (frame sync) are deliberately left unconnected: this
// renderer never reads the panel, and never needs to sync to its refresh.
constexpr int PIN_TFT_SCLK = 12;   // panel "SCL"
constexpr int PIN_TFT_MOSI = 11;   // panel "SDA"
constexpr int PIN_TFT_CS   = 10;
constexpr int PIN_TFT_DC   = 13;
constexpr int PIN_TFT_RST  = 14;
constexpr int PIN_TFT_BL   = 9;    // backlight, on a GPIO so it can be dimmed

constexpr int TFT_WIDTH_PX  = 360;
constexpr int TFT_HEIGHT_PX = 360;

// --- Gesture sensor: PAJ7620U2 over I2C ---------------------------------
//
// 3.3 V ONLY - a 2.8-3.3 V part, and the bare purple breakouts carry no
// regulator. I2C address 0x73. INT is active low.
//
// Not the Arduino default I2C pins (8/9): GPIO 9 is the panel backlight, and
// keeping the display's block contiguous matters more than the default, since
// Wire takes explicit pins anyway.
constexpr int PIN_I2C_SDA     = 17;
constexpr int PIN_I2C_SCL     = 18;
constexpr int PIN_GESTURE_INT = 16;

// --- Status LEDs: 2x WS2812 ---------------------------------------------
//
// Powered from 3V3, NOT 5V. Do not "fix" this back to the 5 V rail.
//
// The 5 V pin reads 0 V on this particular clone board, so the strip was moved
// to 3.3 V during bring-up - and that turned out to be the correct wiring
// regardless. A WS2812 needs a logic high above 0.7*VDD. On a 5 V supply that
// is 3.5 V, which an ESP32 GPIO cannot actually reach, so driving a 5 V strip
// from this board was always marginal and would have been the first suspect
// for any future flicker. At a 3.3 V supply the threshold drops to 2.31 V and
// the same GPIO clears it comfortably.
//
// The trade is that 3.3 V sits just under the WS2812B's nominal 3.5 V minimum.
// It works, and nothing here runs near the part's limits: brightness is capped
// at 64/255 to protect dark adaptation, and two pixels draw roughly 40 mA,
// well inside the onboard regulator.
//
// Pixel 0 is the end nearest the data input - the countdown bar always fills
// from there (see LedPolicy.cpp).
constexpr int PIN_LED_DATA = 15;

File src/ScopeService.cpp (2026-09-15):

#include "ScopeService.h"

#include <Arduino.h>
#include <ctime>
#include <deque>
#include <map>
#include <set>
#include <utility>
#include <vector>

#include "Config.h"
#include "NeoService.h"
#include "Net.h"
#include "PassTask.h"
#include "PsramAllocator.h"
#include "TleFetcher.h"
#include "TleStore.h"

#include "Celestial.h"
#include "MeteorShowers.h"
#include "Projection.h"
#include "Propagator.h"
#include "Solar.h"
#include "StdMagTable.h"
#include "TimeUtils.h"
#include "TleCount.h"
#include "Topocentric.h"
#include "TrainFilter.h"
#include "Visibility.h"

namespace {

// ~200 elsetrec-equivalent objects across `stations`+`visual`, plus headroom
// for up to MAX_TRAIN more from `starlink` (M3). The objects themselves
// (SGP4::Tle/SGP4 payloads, allocated via CoreAlloc in Propagator) live in
// PSRAM regardless of MAX_TRACKED; this cap also bounds PsramVector<Tracked>'s
// own backing array and the per-loop propagation cost.
constexpr int      MAX_TRACKED       = 300;
constexpr uint32_t REFRESH_HOURS     = 12;
constexpr uint32_t BACKOFF_START_MS  = 60UL * 1000UL;      // 1 minute
constexpr uint32_t BACKOFF_MAX_MS    = 60UL * 60UL * 1000UL;  // 60 minutes
constexpr size_t   TRAIL_LEN         = 5;
constexpr uint32_t TRAIL_INTERVAL_MS = 4000;

// A fresh Starlink batch is ~20-60 objects (plan estimate, and matches what
// CelesTrak actually served on 2026-09-04: one 24-member launch). 80 is a
// safe cap that still bounds fetchGroupStreaming()'s `out` vector.
constexpr int MAX_TRAIN = 80;

struct Tracked {
    Tle        tle;
    Propagator prop;
    bool       isTrain = false;   // "starlink" group membership - see Blip::kind
};

// --- Train filter plumbing --------------------------------------------
//
// fetchGroupStreaming() takes a plain `bool(*)(const Tle&)` function pointer
// (see TleFetcher.h) so it never needs to know about std::function or
// capture storage - but the actual predicate (trainfilter::isTrainCandidate)
// needs a runtime "current year" and a threshold. Stash them here before each
// starlink fetch and read them back from this fixed-signature wrapper, which
// is the only thing actually passed as the TleFilter.
int    g_trainCurrentYear = 0;
double g_trainMinMeanMotion = trainfilter::kDefaultMinMeanMotionRevPerDay;

bool trainFilterFn(const Tle& t) {
    trainfilter::Params p;
    p.minMeanMotionRevPerDay = g_trainMinMeanMotion;
    return trainfilter::isTrainCandidate(t, g_trainCurrentYear, p);
}

// Civil (UTC) year for the mean-motion+year train filter. Deliberately not in
// lib/core: TrainFilter.h takes the year as a plain int precisely so the core
// never needs <ctime> or any notion of "now".
int civilYearUtc(int64_t unixSeconds) {
    const time_t t = static_cast<time_t>(unixSeconds);
    struct tm out;
    gmtime_r(&t, &out);
    return out.tm_year + 1900;
}

// Civil (UTC) month/day for MeteorShowers::activeShowers(), same reasoning as
// civilYearUtc() above: activeShowers() takes plain ints so lib/core never
// needs <ctime>. Using UTC rather than the observer's local date matches the
// precedent already set by the train filter's civilYearUtc() - the observer
// here is fixed in Greece (UTC+2/+3), so this can only be off by at most one
// calendar day right at local midnight, never enough to miss or fabricate an
// entire multi-day activity window.
void civilMonthDayUtc(int64_t unixSeconds, int& month, int& day) {
    const time_t t = static_cast<time_t>(unixSeconds);
    struct tm out;
    gmtime_r(&t, &out);
    month = out.tm_mon + 1;
    day   = out.tm_mday;
}

// Backing array lives in PSRAM (see PsramAllocator.h). Note this only
// relocates the vector's own array - each Tracked's Propagator allocates its
// SGP4 payload separately, via CoreAlloc, which is what actually keeps the
// ~200-280 KB of per-object state off the internal heap.
PsramVector<Tracked> tracked;
std::map<int, std::deque<std::pair<double, double>>> trails;

uint32_t nextAttemptMs = 0;
uint32_t backoffMs     = BACKOFF_START_MS;
uint32_t lastTrailMs   = 0;

// Cached copy of the last build() result, refreshed at most once per second
// from loop(). An HTTP request and the status LED both read this instead of
// triggering their own propagation pass over every tracked object - see
// currentSnapshot() below.
Snapshot lastSnapshot;
uint32_t lastBuildMs = 0;

// Which projection build() produces. Not persisted to NVS on purpose: the
// device should come back in SKY mode after a power cut, because that is the
// mode that answers "is anything up right now".
ScopeMode currentMode = ScopeMode::Sky;

// Per-group validation baselines - the last element count that group
// validated and saved successfully. 0 means "no history yet" (fresh install,
// or that group has never had a successful fetch). Deliberately *not* a
// combined total across both groups: "stations" (~21 objects) and "visual"
// (~150+) have wildly different sizes, and checking a small group against a
// large combined total rejects it forever (see FINDING 1, M2 Task 6 fix
// round 1). Seeded from the cached files' own parse counts in begin(), so a
// reboot does not lose the baseline and immediately reject the next refresh.
int stationsPrevCount = 0;
int visualPrevCount   = 0;

// Baseline for the *raw* (pre-filter) starlink parse count - i.e. "does this
// look like the real ~8000-object catalog", never the post-filter train
// count, which is legitimately zero on most days (see attemptRefresh()).
// Unlike stationsPrevCount/visualPrevCount, this is NOT seeded from the
// cached file in begin(): the cache holds only the filtered train members
// (a handful of objects), not the raw catalog, so there is nothing to derive
// a raw-count baseline from after a reboot. It starts at 0 ("no history
// yet") every boot, same as the other two on a fresh install - accepted
// deliberately as a one-cycle gap, matching the reasoning already applied to
// stations/visualPrevCount elsewhere in this file.
int starlinkRawPrevCount = 0;
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

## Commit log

2026-09-02 Add design spec for ESP32-S3 sky radar (M0-M2)
    Standalone ISS/satellite radar on an ESP32-S3 N16R8, rendering to a
    240x240 circular viewport. Core design decision: projection happens in
    the core and renderers are dumb polar plotters, so the browser simulator
    and the future GC9A01 panel consume an identical snapshot.
    Covers data sources (CelesTrak primary, N2YO as test oracle only), the
    visibility engine, pass prediction off the render path, failure states,
    memory rules, and native test strategy.
2026-09-02 Add M0-M1 implementation plan
    Eleven TDD tasks taking the project from empty repo to a board serving a
    live radar of ISS and Tiangong positions. Tasks 1-6 build the natively
    tested orbital core; 7-11 run on hardware.
    Notable: proposes HTTP polling instead of WebSockets (avoids AsyncTCP,
    zero third-party deps) and adds the observer config form the spec
    requires in 4.3.
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2026-09-02 docs: correct the ISS line-1 checksum digit in both plans
    The sample element set had checksum digit 3; the correct mod-10 value is
    1. Caught by Task 3's own checksum test, which is what it is for. The
    Vallado verification TLE was checked and is correct.
2026-09-02 docs: switch SGP4 to dnwrnr/sgp4 (Apache-2.0)
    Vallado's reference implementation is now distributed under AGPL-3.0,
    whose section 13 network clause would force the whole project to AGPL on
    publication. Verified the licence directly rather than assuming.
    Correctness is still checked against Vallado's published verification
    vectors, which are numerical data rather than code. dnwrnr/sgp4 throws on
    error, so both build envs need exceptions enabled and Propagator must
    absorb them.
2026-09-02 feat(core): vendor Apache-2.0 SGP4 and verify against Vallado vectors
    Vendors dnwrnr/sgp4 (Apache-2.0, commit 661e057) under lib/core/src/sgp4/
    and wraps it in Propagator, matching the fixed init/positionAt/epochJd/
    ready contract that Tasks 5, 6 and 10 depend on. Output is TEME km.
    Enables C++ exceptions (-fexceptions, unflag -fno-exceptions) in both the
    native and esp32-s3-devkitc-1 environments, merged with existing flags;
    libsgp4 signals errors by throwing and Propagator::init/positionAt catch
    everything so no exception escapes to callers.
    Verified against Vallado's published SGP4-VER.TLE satellite 00005 vector:
    the propagator reproduces tcppver.out to 8 decimal places at tsince=0
    exac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
2026-09-02 test(core): assert structural well-formedness of multi-element snapshot JSON
    Substring-only assertions in test_snapshot never exercised the blips or
    trail comma-joining logic with more than one element, so a reintroduced
    trailing/leading comma bug would have compiled and passed all 17 tests
    silently. Add a dependency-free wellFormed() bracket/comma validator plus
    tests covering the empty, single-blip, and multi-blip-with-trails cases,
    and verify (then revert) that breaking either comma-join path fails only
    the new multi-element test while all pre-existing tests stay green.
    No production code changed.
2026-09-03 feat(fw): add NVS config and WiFi/NTP bring-up with time-validity gate
    - config: persist Observer lat/lon/alt in NVS via Preferences, hasLocation()
    reports whether a location has ever been stored.
    - net: WiFi STA + NTP bring-up; timeValid() latches true on first successful
    sync and stays true across WiFi drops (RTC keeps running).
    - main: wire config::begin()/net::begin(), report PSRAM size and location
    status at boot, periodic wifi/time/unix status line.
    - platformio.ini: ARDUINO_USB_CDC_ON_BOOT 1 -> 0 for esp32-s3-devkitc-1 so
    Serial routes to UART0 (CH343 bridge on COM6) instead of native USB CDC.
    Verified on hardware (COM6): psram ~8.38MB (8MB octal PSRAM, correct),
    NTP sync acq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
    [Net.cpp, main.cpp]
2026-09-03 docs: correct the PSRAM verification figure
    ESP.getPsramSize() reports the heap-registered size, a couple of KB under
    the raw 8388608 due to allocator bookkeeping. Demanding the exact literal
    would have flagged a healthy board. The real failure signature is 0.
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2026-09-03 fix(fw): replace single pinned root with a 5-root TLS trust store
    A single pinned root violates the project's TLS constraint ("never pin a
    single root - it bricks fetching the day the CA rotates"). setCACert()
    accepts multiple concatenated PEM certs (confirmed against
    mbedtls_x509_crt_parse via ssl_client.cpp), so this swaps the single
    Sectigo pin for five independently-verified self-signed roots covering
    CelesTrak's plausible CA rotation targets: Sectigo Public Server
    Authentication Root R46, USERTrust RSA CA, ISRG Root X1, DigiCert Global
    Root G2, and Amazon Root CA 1. Each pulled from curl.se's Mozilla-derived
    CA bundle (checksum-verified) and independently confirmed self-signed,
    unexpire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
    [TleFetcher.cpp]
2026-09-03 docs: fix Task 10 boot ordering and move-only propagator
    scope::begin() read the LittleFS TLE cache before httpapi::begin()
    mounted the filesystem, so the cache never loaded on cold boot - silently
    defeating the offline resilience the cache exists to provide. Also
    Propagator is move-only, so the plan's push_back(tr) would not compile.
    Both found during Task 10 execution by reading the actual serial log.
2026-09-03 feat(fw): add ScopeService and render live ISS and Tiangong positions
    Ties the SGP4 core, TLE fetch/cache, and HTTP layer together: ScopeService
    tracks parsed element sets, refreshes them on a schedule with backoff,
    samples short trails, and builds ranked/capped Snapshots for the API.
    main.cpp is reordered so httpapi::begin() (which mounts LittleFS) runs
    before scope::begin() (which loads the cached TLE file from it) - the
    brief's literal order silently defeated the offline cache-load path.
    Tracked's Propagator member is move-only, so rebuildFrom() moves into the
    vector instead of copying.
    Cross-checked ISS az/el against n2yo.com's live-tracking backend for the
    temporary Athens placeholder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
    [ScopeService.cpp, main.cpp]
2026-09-03 docs: correct the Task 10 offline expectation
    The plan expected a cold boot with no network to show OFFLINE and draw
    blips. It correctly shows NO TIME and draws nothing: the board has no
    battery-backed RTC, so after a power cycle the clock is unknown and the
    refuse-to-propagate rule wins. OFFLINE is the mid-session-drop path,
    where timeValid() has already latched. Both are now specified.
2026-09-03 fix(fw): prune trails on refresh and make the refresh gate rollover-safe
    Two Important findings from Task 10 fix round 1:
    - rebuildFrom() rebuilt tracked but never touched trails, so a satnum that
    dropped out of the stations group between refreshes left a permanent,
    unbounded entry behind. Now sweeps trails down to the new tracked set's
    satnums at the end of rebuildFrom().
    - scope::loop()'s refresh gate compared millis() >= nextAttemptMs directly,
    which silently stops firing for ~49 days after millis() wraps (a
    pre-wrap nextAttemptMs stays numerically larger than the freshly-wrapped
    millis() for a long time). Switched to the rollover-safe
    int32_t(millis() - nextAttemptMs) >=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
    [ScopeService.cpp]
2026-09-03 docs: fix millis rollover and trail-map leak in Task 10
    The refresh gate compared absolute millis() timestamps, so after the
    ~49.7-day wrap TLE refresh silently stops for up to another 49 days. And
    rebuildFrom() never pruned the trails map, so an object leaving the
    catalogue orphaned its trail permanently.
    Both found by the Task 10 reviewer and proven on hardware.
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2026-09-03 fix(fw): reject NaN/inf/garbage in observer input and poisoned NVS values
    String::toDouble() is a bare strtod(s, NULL): it silently accepts "nan",
    "inf"/"-inf" (which then defeat every range check, since IEEE-754
    comparisons against NaN are always false), and turns non-numeric or
    empty input into 0.0. A NaN observer poisons NVS permanently, bypasses
    the horizon filter in ScopeService, and makes /api/scope emit invalid
    JSON (bare `nan` token), which reads as a dead link on a healthy device.
    Two layers:
    - HttpApi.cpp: parse lat/lon/alt by hand with strtod + an end pointer,
    reject anything that doesn't fully parse or isn't finite, before the
    existing range checks run.
    - Config.cpp: hasLoca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
2026-09-03 docs: reject NaN and garbage in the observer config endpoint
    String::toDouble() is atof(); strtod parses "nan", and NaN comparisons
    are all false, so the range check could not reject it. A NaN reaching NVS
    persisted across reboots, bypassed the horizon filter, and made every
    /api/scope response invalid JSON - a permanently dead radar on a healthy
    board. Confirmed on hardware before fixing.
2026-09-03 fix: validate fetched TLEs before commit, stop re-deriving projection in JS
    Final whole-branch review fix wave for M0-M1 (one blocker, four cheap-now
    items):
    - FIX 1 (blocker): attemptRefresh() now parses and validates the fetched
    body BEFORE touching flash or the freshness stamp. CelesTrak (and a
    truncated TLS read) can return HTTP 200 with a plain-text error body;
    fetchGroup() only checked for a non-empty body. An empty parse, or a
    parse yielding less than half the currently-tracked count, is rejected
    via the normal backoff path without ever calling tlestore::save() or
    markFetched(), so a bad fetch can no longer destroy a good cache and get
    stamped fresh (blocking retry for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
    [ScopeService.cpp, main.cpp]
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2026-09-04 feat(core): add phase angle, apparent magnitude and standard magnitude table
    Implements spec section 13 item 2 (M2 Task 3): phaseAngleRad(), apparentMagnitude(),
    and a stdMagFor() lookup with a documented default for satellites outside the seed
    table. The apparentMagnitude formula is normalised so stdMag is the value returned
    at exactly 1000 km / 90 degree phase, pinned by test.
    Deviations from the task brief's reference code, both needed to pass the given
    unit tests without editing them:
    - MIN_PHASE_FACTOR tightened from 1e-6 to 1e-10 so the fully-backlit case clamps
    to a magnitude the test's floor actually requires (>20), not just "finite".
    - phaseAngleRad's second vector flipped (obser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
    [test_magnitude.cpp]
2026-09-04 fix: revert phaseAngleRad to the standard Sun-satellite-observer convention
    The flip applied in the Task 3 implementation was wrong: independent
    verification of the sun=(1.496e8,0,0) sat=(7000,0,0) site=(6378,0,0)
    geometry confirms the satellite sits between the observer and the Sun,
    so the observer sees its unlit face - phase angle pi, not zero. The
    old test asserting 0 for that geometry had a comment/coordinate
    mismatch and was simply wrong.
    - Magnitude.cpp/.h: restore toObs = (siteEci - satEci), drop the
    flip-justification and Task 9 deferral comments - the convention is
    settled now.
    - test_magnitude.cpp: replace the broken zero-phase test with a
    matched pair (backlit -> pi, fully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
    [test_magnitude.cpp]
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2026-09-04 fix(fw): validate each TLE group against its own history, not the combined total
    The combined tracked.size() (~175) was used as the baseline for both groups.
    stations (~21) checked against it always failed (21*2 < 175), and since the
    two fetches are &&-chained, that broke refresh permanently after the first
    successful two-group merge: markFetched()/rebuildFromGroups() never ran
    again and backoff climbed to 60 min and stayed there.
    Moves the plausibility check into lib/core (tlecount::tleCountIsPlausible,
    natively tested) and tracks a separate previous-count per group in
    ScopeService, seeded from the cached files on boot so a reboot doesn't lose
    the baseline. Verified on hardware: forced a r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
    [Net.cpp, ScopeService.cpp]
2026-09-04 feat(fw): compute real visibility verdicts for every blip
    Wires Visibility::judge() into ScopeService::build() so every tracked
    object's blip carries a real magnitude/visible/reason instead of the
    99.00/false sentinels Tasks 1-5 built the machinery to replace.
    sunEci/siteEci/sunAltDeg are hoisted out of the per-object loop since
    they only depend on the snapshot instant, not the object - recomputing
    solar position ~175 times per build was pure waste. Snapshot gains
    sunAltDeg and Blip gains reason, both emitted in toJson.
    Verified live: at sunAltDeg=55.9-56.0 (Athens, midday) every
    above-horizon blip reads reason=daylight, visible=false - confirming
    the darkness gate's sign/comparison directi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
    [ScopeService.cpp]
2026-09-04 feat(fw): predict visible passes on core 1 and show the countdown
    Finishes Task 8 (M2): the events readout on Snapshot, the PassTask
    background predictor, and the countdown priority in radar.js's status
    line, inherited uncommitted from a prior session and verified here on
    hardware (COM6 / 192.168.31.59).
    Fixed a real startup race in PassTask: the task's very first
    computeOnce() call reliably runs before scope::begin() finishes
    building `tracked` and calls submit() for the first time, so it found
    haveInput still false and slept the full 45-minute recompute interval
    before checking again - silently dead for 45 minutes on every boot.
    computeOnce() now reports whether it had input; taskLoop() r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
    [ScopeService.cpp, main.cpp]
2026-09-04 feat: pulse the onboard RGB LED for imminent visible passes
    Adds LedPolicy (lib/core), a pure function of Snapshot + phase clock so
    every rule is natively tested, and StatusLed (src) which only writes the
    pixel it is handed via neopixelWrite(RGB_BUILTIN, ...) - no policy in
    firmware. Also caches ScopeService's snapshot once per second so the LED
    and every HTTP request stop each triggering their own propagation pass
    over ~175 objects.
    Verified on hardware: GPIO48 (RGB_BUILTIN resolves there via the variant
    header), quiet-sky-is-dark and setup-amber confirmed directly; the
    imminent-pass red pulse confirmed by temporarily widening
    ALERT_WINDOW_SEC onto a real predicted pass, then reverting. vi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
    [ScopeService.cpp, StatusLed.cpp, main.cpp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]
2026-09-04 fix(test): add load-bearing test for brightness cap on colour constants
    The existing test_brightness_never_exceeds_the_cap passes identically whether
    or not the clamp in scale() exists, because all colour constants are already
    bounded by LED_MAX_BRIGHTNESS. It asserts an invariant guaranteed by the
    constants, not by the clamp itself, so it cannot catch a future colour-formula
    change that violates the cap.
    Expose the per-state colour channel maxima as named constexpr values in
    LedPolicy.h with clear documentation. This makes the code more readable and
    allows a new test to directly assert that each constant respects LED_MAX_BRIGHTNESS.
    The clamp in scale() remains as a guard against such futu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
    [ScopeService.cpp, test_ledpolicy.cpp]
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2026-09-04 fix(fw): treat an empty tracked set as stale regardless of timestamp
    `pio run -t uploadfs` rewrites the LittleFS partition holding the TLE
    cache, while the fetch timestamp lives in NVS on a different partition.
    So a filesystem-only deploy left the device serving zero satellites for
    up to REFRESH_HOURS while reporting its data was fresh.
    This was recorded as a deployment hazard during M0-M1 and bit for real
    tonight, minutes before a predicted naked-eye pass. refreshDue() now
    returns true whenever nothing is tracked; attemptRefresh()'s backoff
    still gates retries, so it cannot spin. Verified on hardware: recovered
    in ~70 s and immediately reported 5 visible satellites.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
    [ScopeService.cpp]
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2026-09-05 feat: M4 - meteor shower radiants
    Radiants are almanac data, not orbital mechanics: a fixed equatorial
    position plus an activity window. Adds RA/Dec to horizontal conversion
    (with the asin argument clamped, matching Topocentric and Magnitude), an
    eight-shower table, and radiant rendering on the dial and in the roster.
    The almanac is sourced from the IMO 2026 Meteor Shower Calendar Table 5
    (DOI 10.13140/RG.2.2.36179.08480), read from the PDF directly rather than
    from a summary, with per-figure provenance recorded. Not written from
    memory - this project has already shipped a wrong TLE checksum that way.
    The Quadrantid window crosses the new year (Dec 28 to Jan 12) and that
    case is tested exp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
    [ScopeService.cpp]
2026-09-05 tools: add an onboard-LED pin probe
    The onboard RGB LED has never lit, and the reason is not in the software:
    ledFor() and the snapshot the LED reads are the same one /api/scope
    serialises, and a real alert event was confirmed in it.
    RGB_BUILTIN on the esp32s3 variant is 97, which neopixelWrite() resolves to
    GPIO48. The DevKitC-1 moved that LED to GPIO38 in v1.1, so those were the
    first two candidates - both were driven on their own RMT channels with
    distinct colours, and neither lit anything.
    The probe cannot use neopixelWrite() to compare pins, because in Arduino core
    2.0.7 that function caches its RMT channel in a function-local static and only
    initialises it on the first call. Every la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
    [main.cpp]
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2026-09-05 docs: record the M5 decisions and NEO data provenance
    Two things the design spec left open, resolved here rather than in a comment
    nobody would find:
    "Time-scrubbed over 30 days" did not say how time reaches the dial. A scrub
    control would need an input this device does not have, and a renderer holding
    its own clock state, which breaks the dumb-polar-plotter rule the whole
    architecture rests on. The angle *is* time instead - 0 degrees is now, a full
    turn is the window - so the entire 30 days is legible at once with no control.
    NEO mode also skips the location requirement, because a close approach is an
    Earth-centred event and the dial is meaningful before setup. That is a real
    departure fr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
    [StatusLed.cpp]
2026-09-14 feat: M6 - GC9B72 panel, gesture input, three-LED countdown bar
    Hardware changed under us: a 2.1" 360x360 GC9B72 replaces the planned 240x240
    GC9A01, a PAJ7620U2 gesture sensor replaces the BOOT button, and three external
    WS2812s replace the onboard RGB that could never be lit.
    None of the orbital maths moves. The core already hands renderers (r, theta)
    pairs, so the panel is a drawing routine fed the same snapshot the browser
    gets - which is what stops the two views from drifting apart. Confirming the
    central bet of design spec section 3.1 held under a display swap.
    Panel: LovyanGFX 1.2.29, which carries a Panel_GC9B72 - MIT AND BSD-2-Clause,
    so no repeat of the AGPL problem that ruled ou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
    [enclosure-Body.stl, enclosure-bottom-screwcap.stl, enclosure-front-lid.stl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]
2026-09-15 feat(led): two-pixel countdown bar, not three
    Three WS2812s do not fit the enclosure.
    This is not just a smaller constant. With three pixels the bar staged at 10, 5
    and 1 minutes, and clamping that to two would have left ALERT_STAGE_3_SEC with
    no observable effect - a dead constant every test would still pass without,
    which is the exact failure this project has caught before. So the stage is
    removed rather than clamped: the bar is explicitly two stages, and the finer
    urgency is carried by the pulse rate, which is continuous, needs no pixels, and
    already shrinks from ~2000ms at the window edge to ~400ms on arrival.
    Ws2812.cpp's MAX_PIXELS was 8, which was wrong and would have stayed wrong
    u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
    [enclosure.FCStd]
2026-09-15 fix: three hardware bring-up defects found on the first real wiring
    RMT deadlock in the WS2812 driver. rmtWrite() calls rmt_tx_stop() before
    queuing a frame; if the previous frame is still transmitting, that stop stops
    its TX-done interrupt from ever firing, so the driver's tx semaphore is never
    returned - and rmt_write_items() then waits on it with portMAX_DELAY. Silent,
    permanent deadlock: no crash, no watchdog, just a board that stopped mid-boot
    with no further output. It only surfaced once two frames were issued
    microseconds apart; the 20 Hz update path never collided, so it had been
    sitting latent. rmtWriteBlocking() returns only once the frame has finished,
    guaranteeing the channel is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
    [Display.cpp, ScopeService.cpp, StatusLed.cpp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]
2026-09-15 docs: LEDs run from 3V3, and record M6 as verified
    The strip is powered from 3.3 V, not 5 V, and the comment now says why loudly
    enough that nobody moves it back. The 5 V pin reads 0 V on this clone board, so
    it was moved during bring-up - but it is the correct wiring regardless. A
    WS2812 needs a logic high above 0.7*VDD: on a 5 V supply that is 3.5 V, which
    an ESP32 GPIO cannot reach, so the original wiring was marginal and would have
    been the first suspect for any future flicker. At 3.3 V the threshold is
    2.31 V and the same GPIO clears it comfortably. The trade is sitting just under
    the part's nominal 3.5 V minimum, which costs nothing at the brightness this
    instrument uses.
    The spec now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
    [enclosure.FCStd]
2026-09-16 fix(display): round the NEO time labels to match the web renderer
    A quarter of the 30-day window is 7.5 days. The panel used integer division and
    labelled it +7D while the browser rounded to +8D - the same dial, from the same
    snapshot, showing two different numbers. Cosmetic, but it is precisely the kind
    of drift between renderers that sharing the projection is supposed to make
    impossible.
    [enclosure-front-lid.stl, enclosure-main.stl, enclosure-mainPocket012.stl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]
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2026-09-25 tools: add a display harness diagnostic
    The panel died after being pressed during enclosure fitting - blank screen with
    a working backlight, then smoke from its VCC. That left one question worth
    answering before fitting a replacement: did the ESP32 survive feeding that
    short, and is the soldered harness sound?
    Three automatic checks, none of which need a multimeter, and each of which sees
    something a continuity check cannot:
    Rail shorts An internal pull-up should read high on a floating line. Read
    low and that line is tied to ground; the pull-down case catches
    a line tied to 3.3 V.
    Bridges Drive one line high with every other line pulled down, t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
    [main.cpp]
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2026-09-25 feat(net): optional fixed address, with automatic fallback to DHCP
    This router associates the device perfectly and then never leases it an
    address. That was diagnosed rather than guessed: watching the WiFi events shows
    the station reaching ASSOCIATED and sitting there for 25 seconds with no
    GOT_IP, while an otherwise identical attempt with a fixed address comes up
    instantly at -34 dBm. The radio was never at fault, and neither was the
    password - only DHCP.
    The production firmware could not have shown this. net::loop() logs only on
    success, so "still trying" and "failing every time" looked identical from the
    serial console. The ESP32 emits a reason code on every disconnect and nothing
    was li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
    [Net.cpp, main.cpp]

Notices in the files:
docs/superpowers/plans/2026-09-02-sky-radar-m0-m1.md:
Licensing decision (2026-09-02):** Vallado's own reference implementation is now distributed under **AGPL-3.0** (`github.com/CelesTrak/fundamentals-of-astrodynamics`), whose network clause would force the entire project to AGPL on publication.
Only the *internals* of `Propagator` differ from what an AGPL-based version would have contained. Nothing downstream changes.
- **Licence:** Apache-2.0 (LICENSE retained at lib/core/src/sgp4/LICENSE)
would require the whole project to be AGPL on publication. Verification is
